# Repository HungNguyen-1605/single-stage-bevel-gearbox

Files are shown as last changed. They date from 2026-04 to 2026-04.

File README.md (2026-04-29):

# single-stage-bevel-gearbox
This is the bevel gear box designed courseworks, from random data given by professor. 
In this, i was using Maple for calculating from the top to bottom, choosing every values from catalog specifications, satisfying safety factors of materials for high durability. Visualized model on CAD Mech and 3D version for the second shaft by Inventor.

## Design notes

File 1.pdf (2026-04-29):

TRƯỜNG ĐẠI HỌC SƯ PHẠM KỸ THUẬT TP.HCM KHOA CƠ KHÍ CHẾ TẠO MÁY
BỘ MÔN CƠ SỞ THIẾT KẾ MÁY

0o0

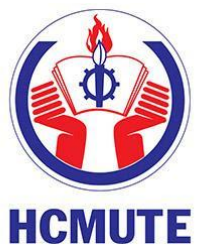
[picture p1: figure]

# THUYẾT MINH TÍNH TOÁN THIẾT KẾ

## ĐỒ ÁN THIẾT KẾ MÁY - MDPR310423

HỌ & TÊN SINH VIÊN: Nguyễn Phi Hùng
MSSV: 23146012
GIẢNG VIÊN HƯỚNG DẪN: TS.Trương Quang Tri GIẢNG VIÊN PHẢN BIỆN:

Tp. HCM, Ngày 08 tháng 01 năm 2026

Trường ĐHSPKT TP.HCM | ĐỒ ÁN THIẾT KẾ MÁY, MMH: MDPR310423
Khoa : Cơ khí Chế tạo máy | THIẾT KẾ HỆ THỐNG THÙNG TRỘN
Bộ môn: Cơ sở Thiết kế máy | Đề số: 03 – Phương án: 06
SVTH: Nguyễn Phi Hùng | MSSV: 23146012
GVHD: Trương Quang Tri | Chữ ký:
Ngày nhận đề: 25/08/2025 | Ngày bảo vệ:
I. Đề bài
Hình 1: Sơ đồ động | Hình 2: Mô hình thùng trộn

Điều kiện làm việc:

- Tải trọng không đổi, quay một chiều
- Thời gian làm việc 5 năm (300 ngày/năm, 2 ca/ngày, 6 giờ/ca)
- Sai số tỉ số truyền hệ thống |∆u/u| ≤ 5%

Số liệu cho trước:

STT | Tên gọi | Giá trị
1 | Năng suất Q (kg/giờ) | 13500
2 | Đường kính D (m) | 0,55
3 | Trọng lượng vật liệu trộn Gv (N) | 2500
4 | Góc nâng vật liệu α (độ) | 83

## Mục lục

1

### 1. Tính toán công suất, tốc độ trục công tác

1.1.Thông số đầu vào
- Năng suất: Q = 13500 (Kg/h)
- Đường kính (trong) thùng trộn: Dtℎung = 0,55 (m)
- Trọng lượng vật liệu trộn: Gvl = 2500 (N)
- Góc nâng vật liệu: α = 83 (độ)
- Các hệ số khác: φ =

1
3

; m =

1
3

; K = 200
1.2.Tốc độ trên trục công tác
Thùng trộn quay liên tục, có nghiêng của thùng so với phương ngang là β = 3

o
, vật
liệu trộn có khối lượng riêng ρ = 1300 (kg/m³
), bán kính Ro =

Dtℎung
3

= 0,1833 (m)
Tốc độ làm việc được suy ra từ công thức: [1], công thức 17-6 trang 23 Q = 60 ⋅ Ft

⋅ φ ⋅ ρ ⋅ L ⋅ m ⋅ nlv ⋅ tan(β)

trong đó: Ft

(m²

) Tiết diện ngang của thùng: Ft =

π⋅Dtℎung

2

4

=

π⋅0,55²

4

= 0,2376 (m²
)

=> L (m): Chiều dài của thùng trộn được tính theo công thức: [1], công thức 17-4 trang 22: L = m ⋅ K ⋅ Dtℎung ⋅ tan(β) =

200⋅0,55⋅tan (3)
3

= 1,9216 (m)

=> Tốc độ làm việc của thùng trộn, nlv (vg/ph):

nlv =

Q
60 ⋅ Ft

⋅ φ ⋅ ρ ⋅ L ⋅ m ⋅ tan(β)

=

13500

60 ⋅ 0,2376 ⋅

1
3

⋅ 1300 ⋅ 1,9216 ⋅

1
3

⋅ tan(β)
= 65,1 (

vg
ph)

Chuyển sang đơn vị (rad/s): ω =

nlv⋅π
30

= 6,818
1.3.Công suất quay trục công tác Ta có: Plv = P1 + P2 + P3
(kW) [1], công thức 17-7 trang 24 Trong đó:
- P1

(kW): Công suất nâng vật liệu lên độ cao thích hợp:

P1 =

Gvl ⋅ Ro ⋅ (1 − cos(α)) ⋅ ω
α ⋅

π
180

=

2500 ⋅ 0,1833 ⋅ (1 − cos(83)) ⋅ 6,818 83 ⋅

π
180
= 1,8942 (kW)

Với bán kính: Ro =

Dtℎung
3

= 0,1833 (m)
- P2

(kW): Công suất trộn vật liệu:
P2 = Gvl ⋅ Ro ⋅ ω ⋅ sin(α) ⋅ 10⁻³ = 2500 ⋅ 0,1833 ⋅ 6,818 ⋅ sin(83) ⋅ 10⁻³ = 3,1014 (kW)
- P3

(kW): Công suất mất mát do ma sát ở ổ trục thùng trộn:
P3 = 0,1 ⋅ (P1 + P2

) = 0,1 ⋅ (1,8942 + 3,1014) = 0,4996 (kW) => Công suất làm việc của thùng trộn (kW): Plv = P1 + P2 + P3 = 5,4952 (kW)

2

Bảng thống kê kết quả tính toán tốc độ và công suất làm việc:

Tốc độ quay của thùng trộn (vg/ph) | nlv = 65,1034 (vg/ph)
Công suất làm việc của trục thùng trộn (kW) | Plv = 5,4952 (kW)

### 2. Chọn động cơ, phân phối tỉ số truyền

2.1.Thông số đầu vào
- Công suất cần thiết chuyển tải liệu vít tải, Plv = 5,4952 (kW)
- Số vòng quay trục vít, nlv = 65,1 (vg/ph)
2.2.Chọn động cơ, phân phối tỉ số truyền
- Công suất cần thiết trên trục động cơ: [2], công thức 2.8, trang 19

Pctđc =

Plv
η

=

5,4952
0,84 = 6,5396 (kW)

η = ηx ⋅ ηbr ⋅ (ηol)

3
⋅ ηkn - hiệu suất truyền động toàn hệ thống ( [2], công thức 2.9, trang 19)
ηx = 0,93 - hiệu suất bộ truyền xích
ηol = 0,99 - hiệu suất truyền động 1 cặp ổ lăn
ηbr = 0,96 - hiệu suất bộ truyền bánh răng côn ηkn = 0.97 - hiệu suất truyền động khớp nối

Tra theo [2] Bảng 2.3, trang 19

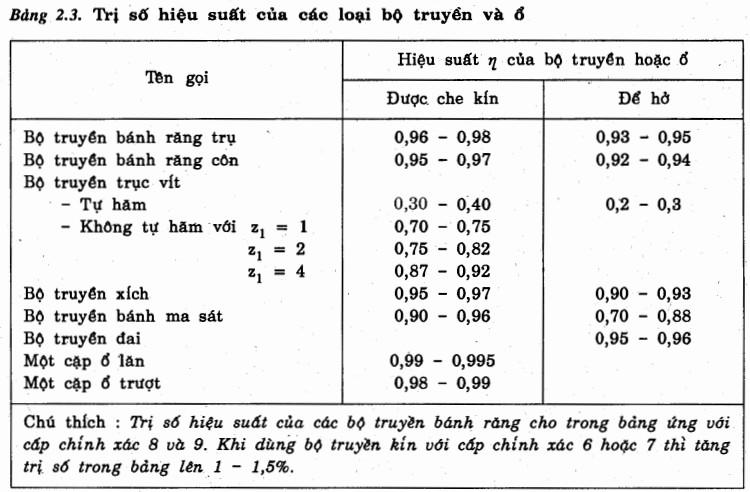
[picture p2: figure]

- Tốc độ quay sơ bộ của động cơ (vg/ph): nsb = usb ⋅ nlv = 10,65 ⋅ 65,1 = 693,35 [2], công thức 2.18, trang 21

Trong đó:

- usb(vô thứ nguyên): Tỉ số truyền sơ bộ của hệ truyền động: usb = ux ⋅ ubr = 3 ⋅ 3,55 = 10,65
ux = 3 | - Tỉ số truyền xích sơ bộ
ubr = 3,55 | - Tỉ số truyền bánh răng sơ bộ
ukn = 1 | - Tỉ số truyền của khớp nối

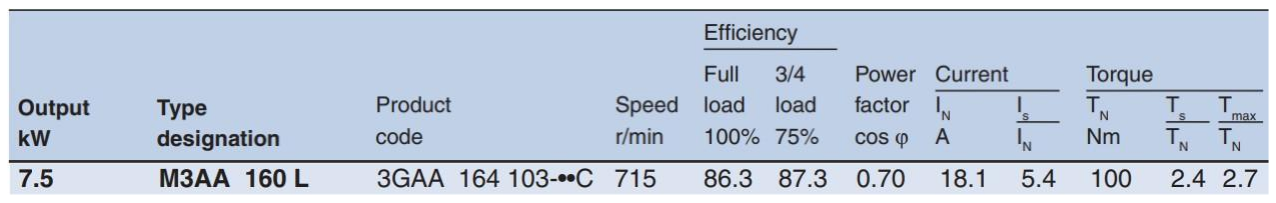
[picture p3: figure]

3

Tra theo bảng 2.4: [2], trang 21

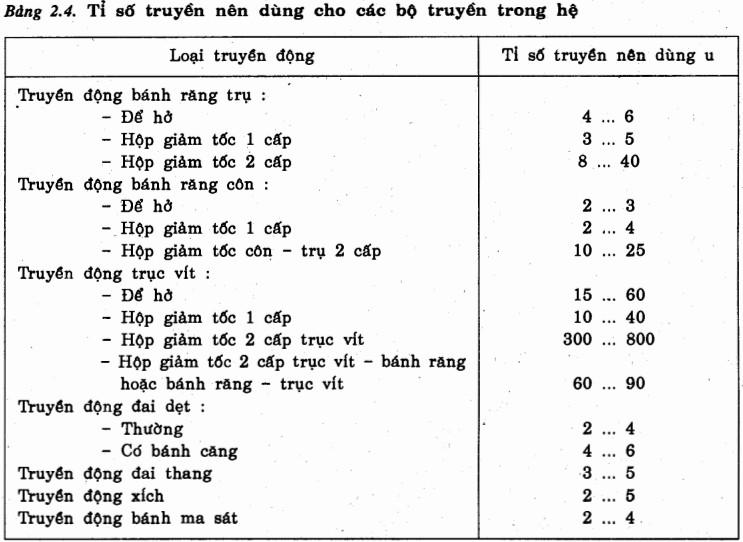
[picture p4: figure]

Điều kiện chọn động cơ: [2], công thức 2.19, trang 22

- Điện áp: 220V
- Tần số: 50Hz
- Công suất động cơ: Pdc ≥ Pctdc
- Tốc độ quay của động cơ: ndc ≈ nsb Bảng chọn kết quả: [3]
Mã động cơ (ABB) | Công suất (kW) | Tốc độ quay (vg/ph) | Ts (90%) Tn | Tmax (90%) Tn
M3AA 160 L | Pdc = 7,5 | ndc = 715 | Ts = 2,16 Tn | Tmax = 2,52 Tn
- Tính tỉ số truyền chung của hệ thống: [4], công thức 3.23, trang 48

ut =

ndc

nlv

=

715
65,1

= 10,98

- Kiểm tra sai số:z

∆u =

|ut − usb|

usb

⋅ 100% =

|10,98 − 10,65|
10,65 = 3,122% < 4%
- Tính TST bộ truyền ngoài

ux =

ut

ubr

=

10,98
3,55 = 3,09

4

2.3.Bảng thông số kỹ thuật hệ thống truyền động

Công suất trên các trục: [2], dựa vào thí dụ h.3.26, trang 49

- Công suất trục công tác (kW): PIII = Plv = 5,4952
- Công suất trục bị dẫn hộp giảm tốc (kW): PII =

PIII

ηx⋅ηol

=

5,4952
0,93⋅0,99

= 5,9685

- Công suất trên trục dẫn hộp giảm tốc (kW): PI =

PII

ηol⋅ηbr

=

5,9685
0,99⋅0,96

= 6,28

- Công suất trên trục động cơ (kW): Ptđc =

PI

ηkn

=

6,28
0,97

= 6,4742

Tốc độ quay của các trục: [2], dựa vào thí dụ h.3.26, trang 49

- Tốc độ quay trục dẫn hộp giảm tốc (vg/ph): n1 =

ndc

ukn

=

715
1

= 715

- Tốc độ quay trục bị dẫn hộp giảm tốc (vg/ph): n2 =

n1

ubr

=

715
3,55

= 201,41

- Tốc độ quay trục công tác (vg/ph): n3 =

n2
ux

=

201,41
3

= 65,10

Moment xoắn trên các trục: [2], dựa vào thí dụ h.3.26, trang 49

- Moment xoắn cần thiết trên trục động cơ (N.mm): Ttdc = 9,55 ⋅ 10⁶ ⋅

Ptdc

ndc

= 86473

- Moment xoắn trên trục dẫn hộp giảm tốc (N.mm): T1 = 9,55 ⋅ 10⁶ ⋅

PI
n1

= 83879

- Moment xoắn trên trục bị dẫn hộp giảm tốc (N.mm):T2 = 9,55 ⋅ 10⁶ ⋅

PII
n2

= 283001

- Moment xoắn trên trục công tác (N.mm): T3 = 9,55 ⋅ 10⁶ ⋅

PIII
n3

= 806085

Bảng thông số kỹ thuật hệ thống truyền động

Trục Thông số | Trục động cơ | Trục I | Trục II | Trục công tác (trục III)
Công suất, P (kW) | Ptđc =6,4742 | PI=6,28 | PII=5,9685 | PIII=5,4952
Tỉ số truyền, u | ukn = 1 | ubr = 3,55 | ux = 3,09
Số vòng quay, n (vg/ph) | ndc = 715 | nI = 715 | nII = 201,41 | nIII = 65,10
Mômen xoắn, T (N.mm) | Ttdc = 86473 | T1 = 883879 | T2 = 283001 | T3 = 806085

### 3. Tính toán, thiết kế bộ truyền xích

3.1.Thông số đầu vào
- PII = P = 5,9685(kW)
- nII = n = 201,41 (vg/ph)
- ux = u = 3,09

5

- Điều kiện làm việc: Tải trọng không đổi, quay một chiều. Thời gian làm việc 5 năm (300 ngày/năm, 2 ca/ngày, 6 giờ/ca)
3.2 Chọn loại xích

Chọn xích ống con lăn, một dãy.

Các thông số hình học xích ống con lăn xem bảng 5.2, tài liệu [2], trang 78

3.3Xác định các thông số xích, bộ truyền xích
- Tính chọn số răng đĩa xích
- Chọn sơ bộ số răng đĩa xích dẫn:
z1 = 29 − 2 ⋅ ux = 22,8 => Chọn z1 = 23 răng
- Chọn số răng đĩa xích bị dẫn:
z2 = z1

⋅ ux = 71,2 => Chọn z2 = 71 răng ≤ zmax = 120 răng
- Tỉ số truyền thực bộ truyền xích: uxtt =

z2
z1

= 3,09

- Xác định bước xích, p, theo điều kiện bền mòn

Hỏng hóc bộ truyền xích đa phần do mòn bản lề, đĩa xích do đó việc tính toán xác định bước xích thường dựa trên chỉ tiêu bền mòn bản lề

Điều kiện đảm bảo chỉ tiêu độ bền mòn, công thức 5.3 tài liệu [2] trang 81

Với xích nhiều dãy: Pt = P ⋅ k ⋅ kz
⋅ kn ≤ [P]

Trong đó:

+ Hệ số kể đến ảnh hưởng số răng đĩa xích dẫn sử dụng cho quá trình thực nghiệm xác định công suất cho phép bảng 5.5 tài liệu [2]. z01 = 25; kz =

z01
z1

=

25
23

= 1,09

+ Hệ số kể đến ảnh hưởng sự khác biệt số vòng quay đĩa xích dẫn sử dụng cho quá trình thực nghiệm xác định công suất cho phép bảng 5.5 tài liệu [2]. n01 = 200, lấy giá trị gần nhất số vòng quay đĩa xích dẫn kn =

n01
n

=

200
201,41

= 0,99

6

+ Hệ số kể đến ảnh hưởng các yếu tố khác công thức 5.4 tài liệu [2] trang 81

k = k0

⋅ ka ⋅ kđc

⋅ kbt ⋅ kđ

⋅ kc = 1 ⋅ 1 ⋅ 1,1 ⋅ 1 ⋅ 1,1 ⋅ 1,25 = 1,51

Trong đó : bảng 5.6 tài liệu [2] trang 82

kđ = 1 + 0,1 | - hệ số tải trọng động tra bảng 4.7, tài liệu [2] trang 55
k0 = 1 | - hệ số kể đến ảnh hưởng của vị trí bộ truyền
ka = 1 | - hệ số kể đến khoảng cách trục và chiều dài xích
kđc = 1,1 | - hệ số kể đến ảnh hưởng của việc điều chỉnh lực căng xích (có đĩa
căng hoặc con lăn căng xích)
kbt = 1 | - hệ số kể đến ảnh hưởng của bôi trơn (không bụi, bôi trơn mức II)
kc = 1,25 | - hệ số kể đến chế độ làm việc của bộ truyền

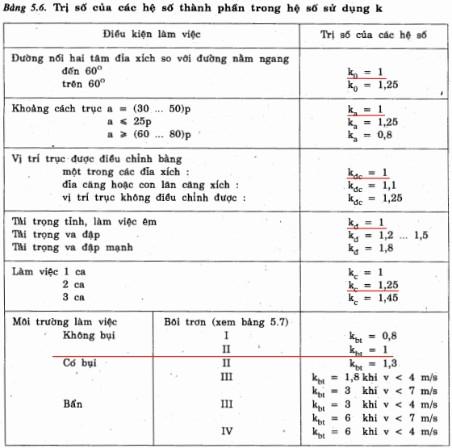
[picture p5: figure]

=>Điều kiện đảm bảo chỉ tiêu độ bền mòn: Pt = 9,7437 (kW)

tra bảng 5.5 tài liệu [2] trang 81

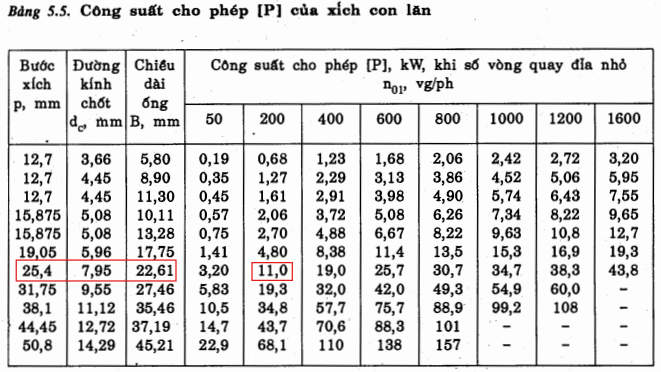
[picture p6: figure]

7

Với Pt = 9,7437 ≤ [P] = 11 (kW), ta có:

- Bước xích (mm): p = 25,4
- Đường kính chốt (mm): dc = 7,95
- Chiều dài ống (mm): B = 22,61

Kiểm tra điều kiện bước xích lớn nhất cho phép: p = 25,4 < pmax = 28,575 mm (thỏa)

- Tính khoảng cách trục và số mắt xích

Chọn sơ bộ khoảng cách trục, a = (30 ÷ 50)p = 762 ÷ 12700 => Chọn axsb =
762 (mm)

Tính số mắt xích, x, theo công thức 5.12 tài liệu [2]

x =

2 ⋅ axsb
p

+

z1 + z2
2

+

(z2 − z1

)

2
⋅ p
4 ⋅ π

2
⋅ axsb

= 2 ⋅

762
25,4

+

23 + 71
2

+

(71 − 23)

2
⋅ 25,4
4 ⋅ π

2
⋅ 762
= 108,9

=> Quy tròn về số nguyên, lấy số mắt xích chẵn xc = 110 răng

Tính khoảng cách trục, a

∗
(mm), sử dụng công thức 5.13 tài liệu [2] tr.85

a

∗ = 0,25p ⋅ {xc − 0,5(z1 + z2 ) + √ (xc + 0,5(z1 + z2
))

2
− 2 (

z2 − z1
π

)

2

}

= 0,25 ⋅ 25,4 ⋅ {110 − 0,5 ⋅ (23 + 71) + √(110 + 0,5 ⋅ (23 + 71))
2

− 2 ⋅ (

71 − 23
π

)

2

= 775,8

Tính lượng giảm khoảng cách trục:

∆a = (0,002 ÷ 0,004) ⋅ a

∗ => Chọn ∆a = 0,002 ⋅ a

∗ = 1,6 (mm)

Khoảng cách trục thiết kế, a = a

∗ − ∆a = 774,3 (mm)

- Tính kiểm nghiệm số lần va đập bản lề xích trong 1 giây, công thức 5.14 tài liệu
[2] trang 85

Trong đó: [i] tra bảng 5.9 [2] trang 85

8

i =

z1

⋅ n
15 ⋅ xc

=

23 ⋅ 201,41
15 ⋅ 110 = 2,81 < [i] = 30

3.4 Kiểm nghiệm xích về độ bền

Một số đại lượng cần thiết để xét điều kiện an toàn:

- Vận tốc xích: v =

n⋅z1⋅p
60000

=

201,41⋅23⋅25,4
60000

= 1,961 (
m
s

)

- Khối lượng một mét xích: q = 2,6 (kg) bảng 5.2
- Hệ số phụ thuộc độ võng f của xích và vị trí bộ truyền: kf = 4
- Tải trọng phá hỏng: Qpℎ = 56700 (N), [2] bảng 5.2 trang 78
- Hệ số tải trọng động: kđ = 1,1

Điều kiện bền theo hệ số an toàn: bảng 5.10 [2]

s =

Qpℎ
kđ

⋅ Ft + F0 + Fv

=

56700
1,1 ⋅ 3043,5 + 79 + 10 = 16,498 ≥ [s] = 8,2

=> Bộ truyền xích đảm bảo bền

- Lực vòng Ft = 1000 ⋅

P
v

= 3043,5 (N)
- Lực căng do lực li tâm sinh ra: Fv = q ⋅ v

2 = 10 (N)
- lực căng do trọng lượng nhánh xích bị động sinh ra, công thức 5.16 tài liệu
[2] F0 = 9,81 ⋅ kf ⋅ q ⋅ a ⋅ 10⁻³ = 79 (N)
- Hệ số an toàn cho phép tra bảng 5.10: [s]
3.5 Xác định các thông số đĩa xích và lực tác dụng lên trục

Đường kính vòng chia các đĩa xích, công thức 5.17 [2] tr.86

d1 =

p
sin(

π
z1

)

=

25,4
sin(

π
23)

= 186,5 (mm) => Chọn d1 = 187 (mm)

d2 =

p
sin(

π
z2

)

=

25,4
sin(

π
71)

= 574,2 (mm)=> Chọn d2 = 574 (mm)

Tính lực tác dụng lên trục

Giả sử:

- Bỏ qua ảnh hưởng lực căng do trọng lượng nhánh xích bị động gây ra - F0
- Bỏ qua ảnh hưởng lực căng do lực li tâm sinh ra - Fv

Công thức 5.20 tài liệu [2] trang 88, ta có:

- kx = 1,15 | - hệ số kể đến trọng lượng xích (bộ truyền nằm ngang hoặc
nghiêng dưới 40

o
- Ft = 3043,5 (N) - lực vòng

=> Fr = kx ⋅ Ft = 1,15 ⋅ 3043,5 = 3500,0 (N)

9

3.6 Bảng thông số kỹ thuật bộ truyền xích

Thông số | Ký hiệu | Giá trị | Đơn vị
Công suất trên trục dẫn | P = PII | 5,9685 | kW
Tốc độ quay trục dẫn | n = nII | 201,4 | vg/ph
Tỉ số truyền thực tế | uxtt | 3,09
Loại xích | xích ống con lăn
Số dãy xích | 1
Số răng đĩa xích dẫn | z1 | 23 | răng
Số răng đĩa xích bị dẫn | z2 | 71 | răng
Bước xích | p | 25,4 | mm
Khoảng cách trục | a | 774 | mm
Đường kính vòng chia đĩa xích dẫn | d1 | 187 | mm
Đường kính vòng chia đĩa xích bị dẫn | d2 | 574 | mm
Lực tác dụng lên trục | Fr | 3500 | N

### 4. Tính toán, thiết kế bộ truyền bánh răng

4.1.Thông số đầu vào
- Công suất trên trục bánh răng dẫn PI = 6,28 (kW)
- Tốc độ quay trục bánh răng dẫn n1 = 715 (vg/ph)
- Tốc độ quay trục bánh răng bị dẫn n2 = 201,41 (vg/ph)
- Tỉ số truyền u = ubr = 3,55
- Góc nghiêng răng β = 0 (BR côn thẳng)
- Mô men xoắn trên trục bánh răng dẫn T1 = 83879 (N.mm)
- Điều kiện làm việc:Tải trọng không đổi. Thời gian làm việc: Thời gian làm việc 5 năm (300 ngày/năm, 2 ca/ngày, 6 giờ/ca). Sai số TST hệ thống |

Δu
u

| ≤ 5%

4.2.Chọn vật liệu

Chọn vật liệu bánh răng: Tùy theo yêu cầu cụ thể như tải trọng lớn hay nhỏ, khả năng công nghệ và thiết bị chế tạo mà có thể chọn vật liệu nhóm I hoặc nhóm II. Tham khảo mục 6.1 [2]

Sau khi chọn vật liệu thống kê các thông tin như ví dụ sau:

| Vật liệu | Nhiệt luyện | Độ cứng (HB) | Giới hạn bền [σb] (Mpa) | Giới hạn chảy [σcℎ ] (Mpa)
BR dẫn | Thép C45 | Tôi cải thiện | HB1 = 230 | [σb1 ] = 750 | [σcℎ1 ] = 450
BR bị dẫn | Thép C45 | Thường hóa | HB2 = 215 | [σb2 ] = 600 | [σcℎ2 ] = 340

10

4.3. Xác định ứng suất cho phép
- Tính [σH1] và [σH2]: theo công thức 6.1a [2] trang 91

[σH1,2

] = σHlim

o
⋅

KHL
SH

(Mpa)

Trong đó:

- [σH1

]: ứng suất tiếp xúc cho phép bánh răng dẫn

- [σH2

]: ứng suất tiếp xúc cho phép bánh răng bị dẫn

- σHlim

o = 2 ⋅ HB1,2 + 70 : ứng suất tiếp xúc cho phép ứng với số chu kỳ cơ sở,

bảng 6.2 [2]

- σHlim1

o = 2HB1 + 70 = 2 ⋅ 230 + 70 = 530 (Mpa)

- σHlim2

o = 2HB2 + 70 = 2 ⋅ 215 + 70 = 500 (Mpa)
- SH = 1,1 : hệ số an toàn khi tính về tiếp xúc, [2] bảng 6.2 trang 94
- KHL = (
NHO

NHE

)

1
mH
: hệ số tuổi thọ xét đến ảnh hưởng thời gian phục vụ mH = 6 ∶

bậc đường cong mỏi khi thử về tiếp xúc (sử dụng cho trường hợp độ cứng HB ≤ 350), [2] bảng 6.7 trang 98

Với: [2] công thức 6.5 trang 93

- NHO = 30 ⋅ HB1,2

2,4
: số chu kỳ thay đổi ứng suất cơ sở khi thử tiếp xúc

=> NHO1 = 30 ⋅ HB1

2,4 = 30 ⋅ 230²,4 = 13972305,13

=> NHO2 = 30 ⋅ HB2

2,4 = 30 ⋅ 215²,4 = 11884298,69

- NHE = 60 ⋅ c ⋅ n ⋅ LH : số chu kỳ thay đổi ứng suất tương đương

c: số lần tiếp xúc/vòng quay

n: số vòng quay

LH = 6 ⋅ 2 ⋅ 300 ⋅ 5 = 18000 (giờ): tổng thời gian phục vụ

=> NHE1 = 60 ⋅ 1 ⋅ n1

⋅ LH = 60 ⋅ 715 ⋅ 18000 = 772200000

=> NHE2 = 60 ⋅ 1 ⋅ n2

⋅ LH = 60 ⋅ 201,41 ⋅ 18000 = 217521127

Chú ý: Trường hợp NHE > NHO thì lấy NHE = NHO và do đó KHL = 1 => KHL1,2 = 1

[σH1

] = σHlim1

o
⋅

KHL1
SH

= 530 ⋅

1
1,1

= 481,8182

[σH2

] = σHlim2

o
⋅

KKL2
SH

⋅

1
1,1

= 454,5455

=> ứng suất tiếp xúc cho phép: [σH] = min{[σH1 ],[σH2

]} = 454,5455 (MPa)

11

- Xác định ứng suất uốn cho phép:

Tính [σF1

] và [σF2

] theo công thức 6.2 [2]

[σF1,2

] =

σHlim

o
⋅ KFC ⋅ KFL
SF

Trong đó:

- σHlim1,2

o = 1,8HB1,2
: ứng suất uốn cho phép ứng với số chu kỳ cơ sở, bảng 6.2

[2]

- σHlim1

o = 1,8HB1 = 1,8 ⋅ 230 = 414 (MPa)

- σHlim2

o = 1,8HB2 = 1,8 ⋅ 215 = 387 (MPa)

- [σF1

]: ứng suất uốn cho phép bánh răng dẫn

- [σF2

]: ứng suất uốn cho phép bánh răng bị dẫn
- KFC = 1: hệ số xét đến ảnh hưởng đặt tải (đặt tải một phía, quay một chiều)
- SF = 1,75 : hệ số an toàn khi tính về uốn, bảng 6.2 [2] trang 94
- KFL = (
NFO

NFE

)

1
mF
: hệ số tuổi thọ xét đến ảnh hưởng chế độ tải trọng (mF = mH)

Với: NFE = 60 ⋅ c ⋅ n ⋅ LH: số chu kỳ thay đổi ứng suất tương đương

NFO = 4 ⋅ 10⁶
: số chu kỳ thay đổi ứng suất cơ sở khi thử uốn (áp dụng cho tất cả các loại thép, trang 93 [2])

NFE1 = NHE1 = 772200000 và NFE2 = NHE2 = 217521127

Chú ý: Vì NFE > NFO nên lấy NFE = NFO, và do đó KFL = 1

=> ứng suất uốn cho phép: [σF1
] = 236,5714 (Mpa) và [σF2

] = 221,1429 (Mpa)

- Ứng suất cho phép khi quá tải:

[σH]max (Mpa): (trong điều kiện nhiệt luyện thường hóa hoặc tôi cải thiện) công thức 6.13 [2] trang 95

[σH1

]max = 2,8σcℎ1 = 2,8 ⋅ 450 = 1260

[σH2

]max = 2,8σcℎ2 = 2,8 ⋅ 340 = 952

=> [σH]max = min {[σH1

]max,[σH2

]max} = 952 (Mpa)

[σF]max (Mpa): (trường hợp vật liệu có HB ≤ 350) theo công thức 6.14 [2] trang 96:

[σF1

]max = 0,8σcℎ1 = 0,8 ⋅ 450 = 360

[σF2

]max = 0,8σcℎ2 = 0,8 ⋅ 340 = 272

12

4.4. Xác định sơ bộ chiều dài côn ngoài
- Xác định sơ bộ chiều dài côn ngoài theo công thức 6.52a [2]

Re = KR ⋅ √u

2 + 1 ⋅ √
T1

⋅ KHβ
(1 − Kbe) ⋅ Kbe ⋅ u ⋅ [σH]

2

3

= 49,5 ⋅ √3,55² + 1 ⋅ √
83879 ⋅ 1,128
(1 − 0,25) ⋅ 0,25 ⋅ 3,55 ⋅ 454,5455²

3
= 161,2 (mm)

Trong đó:

- KR = 49,5 : hệ số phụ thuộc vật liệu thép - thép, răng thẳng
- Kbe = 0,25 : hệ số chiều rộng vành răng (u = 3,55 ≥ 3)
- KHβ = 1,128 : hệ số kể đến sự phân bố không đều tải trọng trên chiều rộng

vành răng bánh răng côn (tra bảng 6.21 [2] và nội suy) với

Kbe⋅u
2−Kbe

= 0,51

- [σH] = 454,5455 (Mpa) : ứng suất tiếp xúc cho phép 4.5.Xác định các thông số ăn khớp
- Đường kính chia ngoài bánh dẫn tính theo công thức 6.52b [2]

de1 =

2 ⋅ Re
√1 + u
2

=

2 ⋅ 161,2
√1 + 3,55²

= 87,4 (mm)

Xác định số răng bánh dẫn: Tính theo công thức de1 và tỉ số truyền u kết hợp phương pháp nội suy rồi tra bảng 6.22 [2]

+ Chọn được Z1p = 18
+ Số răng bánh dẫn của bánh răng côn z1 = 1,6 ⋅ Z1p = 28,8 => Chọn số nguyên z1 = 28 răng
- Tính đường kính trung bình: theo công thức 6.54 [2]: dm1 = (1 − 0,5Kbe) ⋅ de1 = (1 − 0,5 ⋅ 0,25) ⋅ 87,4 = 76,5 (mm)
- Tính mô đun trung bình theo công thức 6.56 [2]: mtm =

dm1
z1

=

76,5
28

= 2,7 (mm)

13

- Xác định mô đun vòng ngoài: mte =

mtm
1−0,5Kbe

=

2,7
1−0,5⋅0,25

= 3,1 (mm) [2] công thức

6.56

Chọn theo tiêu chuẩn bảng 6.8 [2]: mte = 4 (mm) (ưu tiên chọn dãy 1)

- Tính lại mô đun vòng trung bình theo mô đun tiêu chuẩn

mtm = mte ⋅ (1 − 0,5 ⋅ Kbe) = 4 ⋅ (1 − 0,5 ⋅ 0,25) = 3,5 (mm)

- Tính lại số răng z1
theo công thức: z1 =

dm1

mtm

=

76,5
3,5

= 21,85 => Chọn z1 = 22 răng

- Tính số răng bánh bị dẫn z2
: z2 = u ⋅ z1 = 3,55 ⋅ 22 = 78,1 => Chọn z2 = 78 răng
- Tỉ số truyền thực tế của bộ truyền bánh răng côn: ubrtt =

z2
z1

= 3,545

- Tính sai lệch tỉ số truyền hệ thống, kiểm tra điều kiện đầu bài Δuℎệ tℎống ≤ 5%

Δuℎệ tℎống =

ucℎ − ubrtt ⋅ uxtt

ucℎ

⋅ 100% = 0,345 ≤ 5%

Trong đó:

uxtt = 3,09 | - tỉ số truyền thực bộ truyền xích
ubrtt = 3,545 | - tỉ số truyền thực bộ truyền bánh răng
ucℎ = 10,98 | - tỉ số truyền chung của hệ thống
- Xác định các góc ôm chia theo công thức
| δ1 = tan⁻¹ ( z1 z2 ) = tan⁻¹ (
| 27
96) = 15,75 (độ)
| δ2 = 90 − δ1 = 90 − 15,71 = 74,25 (độ)
- Xác định đường kính trung bình, chiều dài côn ngoài theo công thức 6.65 và 6.66 [2] + Đường kính chia ngoài:
Re = 0,5 ⋅ mte ⋅ √z1 | 2 + z2 2 = 4⋅√22²+78²
| 2 = 162,1 (mm) => Chọn: Re = 162 (mm)
+ Bề rộng vành răng:

b = Kbe ⋅ Re = 0,25 ⋅ 162 = 40,525 (mm) => Chọn b = 40,5 (mm)

4.6.Xác định các kích thước hình học theo tiêu chuẩn mô đun
- Đường kính vòng chia bánh dẫn (mm): de1 = mte ⋅ z1 = 4 ⋅ 22 = 88
- Đường kính vòng chia bánh bị dẫn (mm): de2 = mte ⋅ z2 = 4 ⋅ 78 = 312

14

- Chiều cao răng ngoài (mm): ℎe = 2 ⋅ ℎte ⋅ mte + c = 8,8 (với hte = 1; c = 0,8; xn1 = 0,38; mte = 4 )
- Chiều cao đầu răng ngoài bánh dẫn (mm):

ℎae1 = ℎte + xn1

⋅ cos(β) ⋅ mte = 1 + 0,38 ⋅ cos (0) = 2,52

- Chiều cao chân răng ngoài bánh dẫn (mm):

ℎfe1 = ℎe − ℎae1 = 8,8 − 2,52 = 6,28

- Chiều cao đầu răng ngoài bánh bị dẫn (mm):

ℎae2 = 2 ⋅ ℎte ⋅ mte − ℎae1 = 2 ⋅ 1 ⋅ 4 − 2,52 = 5,48

- Chiều cao chân răng ngoài bánh bị dẫn (mm):

ℎfe2 = ℎe − ℎae2 = 8,8 − 5,48 = 3,32

- Đường kính đỉnh răng ngoài bánh dẫn (mm):

da1 = de1 + 2 ⋅ ℎae1

⋅ cos(δ1

) = 88 + 2 ⋅ 2,52 ⋅ cos(15,75) = 92,9

=> chọn da1 = 93 (mm)

- Đường kính đỉnh răng ngoài bánh bị dẫn (mm):

da2 = de2 + 2 ⋅ ℎae2

⋅ cos(δ2) = 312 + 2 ⋅ 5,48 ⋅ cos (74,25) = 314,98

=> chọn da2 = 315 (mm)

- Đường kính trung bình bánh dẫn (mm): dm1 = (1 −
0,5b
Re

) ⋅ de1 = (1 −
0,5⋅40,5

162 ) ⋅ 88 = 77 => chọn dm1 = 77 (mm)

- Đường kính trung bình bánh bị dẫn (mm): dm2 = (1 −
0,5b
Re

) ⋅ de2 = (1 −
0,5⋅40,5

162 ) ⋅ 312 = 273 => chọn dm2 = 273 (mm)

4.7.Kiểm nghiệm bền
- Kiểm nghiệm độ bền tiếp xúc

σH = ZMZHZε√
2T1KH ⋅ √u
2 + 1
0,85 ⋅ b ⋅ u ⋅ dm1

2 ≤ [σH]

Trong đó:

- ZM = 274 : hệ số kể đến cơ tính vật liệu của các bánh răng ăn khớp, bảng 6.5 [2] tr.96
- ZH = 1,76 : hệ số kể đến hình dạng bề mặt tiếp xúc, bảng 6.12 [2] tr.106
- Zε hệ số kể đến sự trùng khớp của răng Zε = √
4−εα
3
= √ | 4−1,694
| 3 = 0,87

Với: εα = [1,88 − 3,2 ⋅ (
1
z1

+

1
z2

)] ⋅ cos(β) = [1,88 − 3,2 ⋅ (
| 1
| 22 +

1

78) ⋅ cos(0)] = 1,69

15

+ KH = KHβ ⋅ KHα ⋅ KHv : hệ số tải trọng khi tính về tiếp xúc

Với:

+KHβ = 1,128 : hệ số kể đến sự phân bố không đều tải trọng trên chiều rộng vành

rang
+KHα = 1 : hệ số kể đến sự phân bố không đều tải trọng cho các đôi răng đồng thời ăn khớp (tra bảng 6.14 [2] tr.107, bánh răng côn răng thẳng = 1)
+KHv hệ số kể đến tải trọng động xuất hiện trong vùng ăn khớp:

KHv = 1 +

vH ⋅ b ⋅ dm1

2T1KHβKHα

= 1,07

Trong đó: vH = δH ⋅ go ⋅ v ⋅ √
dm1(u+1)
u

= 4,269 < vHmax = 310

Với: v =

π⋅dm1⋅n1
60000

=

π⋅77⋅715
60000

= 2,883
- δH = 0,006 (δF = 0,016): hệ số kể đến ảnh hưởng của các sai số ăn khớp, tra bảng 6.15 [2]

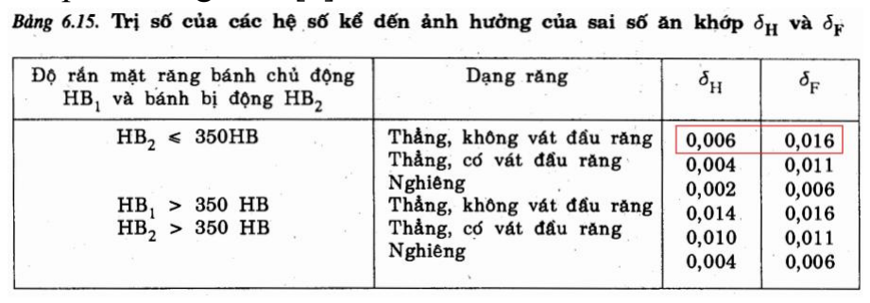
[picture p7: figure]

- go = 53 : hệ số kể đến ảnh hưởng của sai lệch các bước răng, tra bảng 6.16 [2]
- vmax = 310 (m/s): xác định từ khả năng chịu tải trọng động lớn của bánh răng, bảng 6.17 [2]

=> Hệ số tải trọng khi tính về tiếp xúc KH = KHβ ⋅ KHα ⋅ KHv = 1,21

=> Ứng suất tiếp xúc: σH = 429,3397 (Mpa) < [σH] = 454,5455 (Mpa)

16

Cần phải kiểm tra điều kiện: (trường hợp σH < [σH] )

[σH] − σH
[σH]

⋅ 100% =

454,5455 − 429,3397
454,5455 ⋅ 100% = 5,5453% ≤ 10% (thỏa)
- Kiểm nghiệm răng về độ bền uốn

Tính ứng suất uốn, và kiểm tra điều kiện bền uốn theo công thức 6.65 và 6.66 [2]

σF1 =

2T1KFYF1YεYβ
0,85 ⋅ b ⋅ mtm ⋅ dm1

= 74,137 ≤ [σF1

| ] = 236,571 (Mpa)

σF2 =

σF1YF2

YF1

= 68,434 ≤ [σF2

| ] = 221,143 (Mpa)

Trong đó:

- Yε =

1
εα

= 0,59 : hệ số kể đến sự trùng khớp của răng

- Yβ = 1 : hệ số kể đến độ nghiêng của răng
- YF1 = 4 : hệ số dạng răng của bánh dẫn, tra bảng 6.18 [2] với zv1 =
| z1
| cos³(β) = 22
- YF2 = 3,611 : hệ số dạng răng của bánh bị dẫn với zv2 =
| z2
| cos³(β) = 78

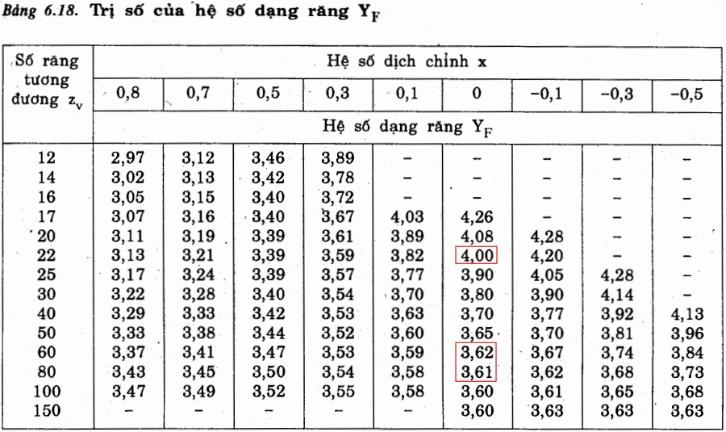
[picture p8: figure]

- KF = KFβ ⋅ KFα ⋅ KFv = 1,92 : hệ số tải trọng khi tính về uốn

Với:

+ KFβ = 1,47 : hệ số kể đến sự phân bố không đều tải trọng trên chiều rộng vành răng khi tính về uốn, tra bảng 6.21 [2]
+ KFα = 1 : hệ số kể đến sự phân bố không đều tải trọng cho các đôi răng đồng thời ăn khớp khi tính về uốn, tra bảng 6.14 [2]
+ KFv hệ số kể đến tải trọng động xuất hiện trong vùng ăn khớp khi tính về uốn tính, công thức 6.68 [2] KFv = 1 +
| vF⋅b⋅dm1 2T1KFβKFα = 1,31
| Với: vF = δF ⋅ go ⋅ v √ dm1⋅(u+1) u = 24,284

17

- Kiểm nghiệm răng về quá tải: Kqt = 1 : hệ số quá tải
=> Kiểm tra ứng suất tiếp xúc cực đại cho phép theo công thức 6.48 [2]

σHmax = σH ⋅ √Kqt = 447,713 (Mpa) ≤ [σH]max = 952 (MPa)

=> Kiểm tra ứng suất uốn cực đại cho phép theo công thức 6.49 [2]

σF1max = σF1

⋅ Kqt = 74,137 (Mpa) ≤ [σF1

]max = 360 (Mpa)

σF2max = σF2

⋅ Kqt = 68,434 (Mpa) ≤ [σF2

]max = 272 (Mpa)

4.8.Tính luật tác dụng khi ăn khớp α = 20o

: góc ăn khớp, thường lấy 20o

- Lực vòng (N): Ft1 =

2T1

dm1

= 2178,5 (N) = Ft2

- Lực hướng tâm (N): Fr1 = Ft1

⋅ tan(α) ⋅ cos(δ1

) = 763,1 = Fa2
- Lực dọc trục (N): Fa1 = Ft1

⋅ tan(α) ⋅ sin(δ1

) = 215,3 = Fr2

4.9. Bảng thông số kỹ thuật bộ truyền bánh răng
Thông số | Ký hiệu | Giá trị | Đơn vị
Công suất trục bánh răng dẫn | PI | 6,28 | kW
Tốc độ quay trục dẫn | n1 | 715 | Vg/ph
Mô men xoắn trên trục dẫn | T1 | 83879 | N.mm
Tỉ số truyền thực tế | ubrtt | 3,545
Thời gian làm việc | LH | 18000 | Giờ
Chiều dài côn ngoài | Re | 162 | mm
Mô đun vòng ngoài | mte | 4 | mm
Chiều rộng vành răng | b | 40.5 | mm
Góc côn chia bánh dẫn | δ1 | 15,75 | Độ
Góc côn chia bánh bị dẫn | δ2 | 74,25 | Độ
Số răng bánh dẫn | z1 | 22 | Răng
Số răng bánh bị dẫn | z2 | 78 | Răng
Đường kính vòng chia bánh dẫn | de1 | 88 | mm
Đường kính vòng chia bánh bị dẫn | de2 | 312 | mm
Đường kính đỉnh răng ngoài bánh dẫn | da1 | 93 | mm
Đường kính đỉnh răng ngoài bánh bị dẫn | da2 | 315 | mm
Đường kính trung bình bánh dẫn | dm1 | 77 | mm
Đường kính trung bình bánh bị dẫn | dm2 | 273 | mm
Chiều cao đầu răng ngoài bánh dẫn | ℎae1 | 2.52 | mm
Chiều cao đầu răng ngoài bánh bị dẫn | ℎae2 | 5.48 | mm

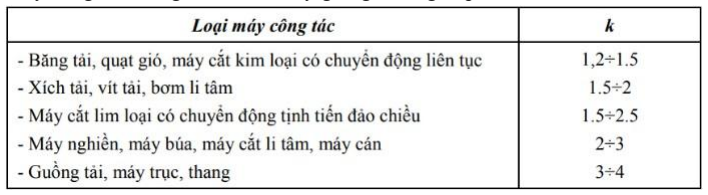
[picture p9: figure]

18

Chiều cao chân răng bánh dẫn | ℎfe1 | 6.28 | mm
Chiều cao chân răng bánh bị dẫn | ℎfe2 | 3.32 | mm

Lực tác dụng ăn khớp
Lực vòng | Ft1,2 | 2178,5 | mm
Lực hướng tâm | Fr1 = Fa2 | 763,1 | mm
Lực dọc trục | Fa1 = Fr2 | 215,2 | mm

### 5. Tính chọn nối trục

5.1.Thông số đầu vào
- Moment xoắn danh nghĩa cần truyền (trục vào): T = Ttdc = 86473 (N.mm)
- Đặc trưng tải trọng: Thùng trộn
5.2. Chọn nối trục
- Xác định moment xoắn tính toán T = Ttdc = 86473 (N.mm)
+ Mômen xoắn danh nghĩa trên trục
+ Hệ số an toàn làm việc, phụ thuộc vào loại máy công tác, tra bảng 9.1 [4] tr.229, máy công tác thùng trộn có thể lấy giống trường hợp vít tải k = 1,5

=> Moment xoắn tính toán trục vào: Tt = k ⋅ T ⋅ 10⁻³ = 130 (N. m)

- Tính sơ bộ đường kính trục tại vị trí lắp nối trục
+ Moment xoắn cần truyền trên trục lắp nối trục T = 86473,3147 (N.mm)
+ Ứng suất trượt cho phép. Giả sử chọn vật liệu làm trục là thép 45
[τ] = 15 ÷ 30 (Mpa). Với hộp giảm tốc, trị số nhỏ sử dụng cho trục dẫn – trục vào τv = 15 (Mpa); trị số lớn sử dụng cho trục bị dẫn – trục ra τr = 30 (Mpa)

=> Tính đường kính trục sơ bộ tại vị trí lắp nối trục

d ≥ √
Tt
0,2⋅τv

⋅ 10³

3

= √
130
0,2⋅15

3
= 35,1 (mm) => Chọn theo tiêu chuẩn d = 36 (mm)

Dựa trên giá trị moment xoắn tính toán, đường kính trục sơ bộ ở bước trên, chọn nối trục phù hợp theo bảng 9.10a, kích thước vòng đàn hồi, chốt bảng 9.10b [4] tr.239

19

Bảng 9.10a Kích thước cơ bản của nối trục vòng đàn hồi [4]

Bảng 9.10b Kích thước cơ bản của vòng đàn hồi [4] với Tt = 130 (N.mm)

Thông số tính toán cơ bản của nối trục:

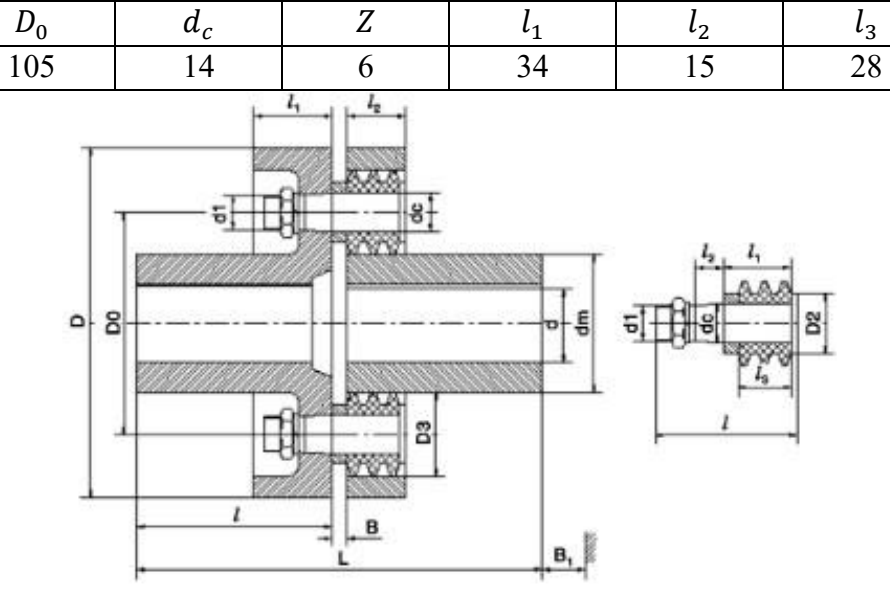
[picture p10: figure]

Hình nối trục vòng đàn hồi

5.3. Tính kiểm nghiệm bền
- Điều kiện sức bền dập của vòng đàn hồi theo công thức (9.11) [5]

σd =

2 ⋅ k ⋅ T
Z ⋅ D0

⋅ dc

⋅ l3

=

2 ⋅ 1,5 ⋅ 86473
6 ⋅ 105 ⋅ 14 ⋅ 28 = 1,05 ≤ [σd

] = 2 (Mpa)

- Điều kiện sức bền uốn của chốt theo công thức (9.12) [5]

σu =

k ⋅ T ⋅ l0
0,1 ⋅ D0

⋅ dc

3
⋅ Z

=

k ⋅ T ⋅ (l1 +

l2
2

)

0,1 ⋅ D0

⋅ dc

3
⋅ Z

=

1,5 ⋅ 86473 ⋅ 41,5
0,1 ⋅ 105 ⋅ 14³
⋅ 6

= 31,14 ≤ [σu

] = 60 (Mpa)

20

5.4. Tính lực tác dụng lên trục
- Tính lực hướng tâm nối trục Frnt, sinh ra do sự không đồng tâm khi lắp hai nửa khớp nối lên các trục, giá trị Frnt có thể lấy gần đúng như sau:

Frnt =

0,2 ⋅ 2 ⋅ T
D0

=

0,2 ⋅ 2 ⋅ 86473
14 = 329,4 (N)
- Moment xoắn: T = Ttdc = 86473

### 6. Tính toán thiết kế trục và chọn then

6.1. Thông số đầu vào

Trục 1
lực tác dụng lên trục từ bộ truyền xích (N) | Frx = 3500
moment xoắn trên trục I (N.mm) | T1 = 83879
góc nghiêng bộ truyền xích (độ) | α = 30
lực nối trục (lực hướng tâm) (N) | Frnt = 329,4
lực tiếp tuyến (lực vòng) bộ truyền bánh răng (N) | Ft1 = 2178,5
lực hướng tâm bộ truyền bánh răng (N) | Fr1 = 763,1
lực dọc trục bộ truyền bánh răng (N) | Fa1 = 215,2
đường kính trung bình bánh dẫn (mm) | dm1 = 77

Trục 2
lực dọc trục bộ truyền bánh răng (N) | Fa2 = 763,1
lực hướng tâm bộ truyền bánh răng (N) | Fr2 = 215,2
lực tiếp tuyến (lực vòng) bộ truyền bánh răng (N) | Ft2 = 2178,5
moment xoắn cần truyền trên trục (N.mm) | T2 = 283001
lực tác dụng lên trục từ bộ truyền xích (N) | Frx = 3500
góc nghiêng bộ truyền xích (độ) | α = 30
đường kính trung bình bánh bị dẫn (mm) | dm2 = 273

6.2.Chọn vật liệu

Vật liệu | Nhiệt luyện | Độ cứng (HB) | Giới hạn bền σb (Mpa) | Giới hạn chảy σcℎ (Mpa)
Thép C45 | Tôi cải thiện | HB = 250 | σb = 850 | σcℎ = 580

21

6.3. TÍnh toán thiết kế trục theo điều kiện bền, chọn then
- Sơ đồ động:

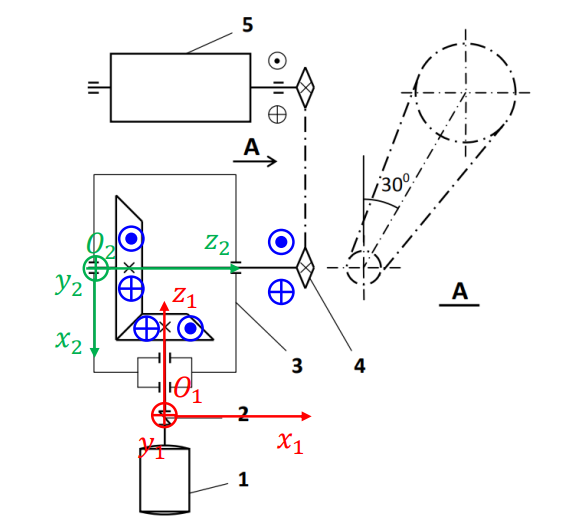
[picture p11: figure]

Xác định sơ bộ đường kích trục theo điều kiện bền cắt

- Đường kính trục 1 sơ bộ với τv = 15 (MPa)

d ≥ √
T1
0,2⋅τv

3

= √
83879
0,2⋅15

3
= 30,4 => Chọn d1 = 35 (mm)
- Đường kính trục 2 sơ bộ với τr = 30 (MPa)

d ≥ √
T2
0,2⋅τv

3

= √
283001
0,2⋅30

3
= 36,1 => Chọn d2 = 40 (mm)
- Xác định chiều dài các đoạn trục, khoảng cách giữa các gối đỡ và điểm đặt lực theo hình 10.10 [2]
+ Bề rộng ổ theo bảng 10.2 [2] tr.189
- Trên trục 1: b01 = 21 (mm)
- Trên trục 2: b02 = 23 (mm)
+ Chiều dài mayơ nửa khớp nối i = 2 trên trục thứ nhất k = 1
lm12 = (1,4 ÷ 2,5) ⋅ d1 = 1,4 ⋅ d1 = 1,4 ⋅ 35 = 49 (mm) + Chiều dài mayơ bánh bánh răng côn i = 3 trên trục thứ nhất k = 1 lm13 = (1,2 ÷ 1,4) ⋅ d1 = 1,2 ⋅ d1 = 1,2 ⋅ 35 = 42 (mm) + Chiều dài mayơ đĩa xích i = 2 trên trục thứ hai k = 2
lm22 = (1,2 ÷ 1,5) ⋅ d2 = 1,2 ⋅ d2 = 1,2 ⋅ 40 = 48 (mm) + Chiều dài mayơ bánh răng côn i = 3 trên trục thứ hai k = 2 lm23 = (1,2 ÷ 1,4) ⋅ d2 = 1,2 ⋅ d2 = 1,2 ⋅ 40 = 48 (mm) + Trị số của các khoảng cách, xác định theo bảng 10.3 [2] tr.189 k1 = 10; k2 = 10; k3 = 10; ℎn = 25,6

22

+ | Khoảng trục công xôn chìa ra ngoài gắn với bánh đai, nối trục,lc12, lc22 tính
| theo công thức 10.14 [4]

lc12 =

(lm12 + b01)
2

+ k3 + ℎn =

49 + 21
2

+ 10 + 25,6 = 70,6 (mm)

lc22 =

(lm22 + b02)
2

+ k3 + ℎn =

48 + 23
2

10 + 25,6 = 71,1 (mm)

+ | Khoảng cách từ gối đỡ 0 đến 1 theo bảng 10.4
| l11 = (2,5 ÷ 3) ⋅ d1 = 2,5 ⋅ d1 = 2,5 ⋅ 35 = 87,5 (mm)
+ | Khoảng cách từ gối đỡ 0 đến 1 theo bảng 10.4
| l12 = −lc12 = −65 (mm) (nằm bên trái ổ lăn gốc B)
+ | Khoảng cách từ gối đỡ 0 đến bánh răng theo bảng 10.4:
| l13 = l11 + k1 + k2 + lm13 + 0,5 ⋅ (b01 − b13 ⋅ cos(δ1 ))
| = 87,5 + 10 + 10 + 42 + 0,5 ⋅ (21 − 40,5 ⋅ cos(15,75)) = 140,5 (mm)
+ Khoảng cách từ gối đỡ 0 đến trục đối xứng nằm giữa ổ lăn 0 và ổ lăn 1:
| X = dm1
| 2 + lm23 + k1 + k2 + b0
| 2 − 7
| =
| 77
| 2 + 48 + 10 + 10 +
| 23
| 2 − 7 = 111 (mm)
+ Khoảng cách từ gối đỡ 0 đến gối đỡ 1: l21 = 2 ⋅ X = 2 ⋅ 111 = 222 (mm) + Khoảng cách từ gối đỡ 0 đến đĩa xích: lc22 = 71,1 (mm)
+ Khoảng cách từ gối đỡ 0 đến bánh răng theo bảng:
| l23 = X + dm1
| 2 = 111 +
| 77
| 2 = 149,5 (mm)

Lưu ý: l21, l23 được tính theo ngữ cảnh hộp giảm tốc 1 cấp

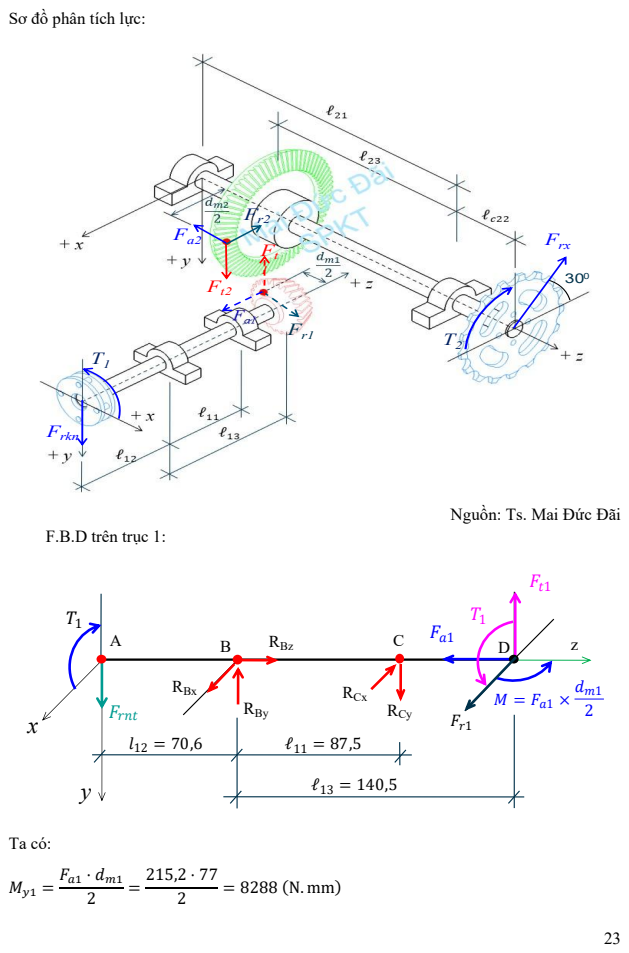
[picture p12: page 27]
F.B.D trên trục 1:; RBy; RCx; RCy; RBx

Sơ đồ phân tích lực:

Nguồn: Ts. Mai Đức Đãi

24

- Xét mặt phẳng YOZ:
ΣMB = −Frnt ⋅ l12 + RCy ⋅ l11 − Ft1

⋅ l13 = 0
=> RCy =

Frnt⋅l12+Ft1⋅l13
l11

=

329,4⋅70,6+2178,5⋅140,5
87,5

= 3764,1(N)

ΣFy = Frnt − RBy + RCy − Ft1 = 0

=> RBy = Frnt + RCy − Ft1 = 329,4 + 3764,1 − 2178,5 = 1915 (N)

- Xét mặt phẳng XOZ

ΣMB = −RCx ⋅ l11 + Fr1

⋅ l13 − My1 = 0

=> RCx =

Fr1⋅l13−My1
l11

=

763,1⋅140,5−8287,5
87,5

= 1130,7 (N)

ΣFx = RBx − RCx + Fr1 = 0

=> RBx = RCx − Fr1 = 1130,7 − 763,1 = 367,6 (N)

Thông số đầu vào trục 1:

Frnt = 329,4 | N
T = 83879 | N.mm
RBx = 367,6 | N
RBy = 1915 | N
RCx = 1130,7 | N
RCy = 3764,1 | N
Fa1 = 215,2 | N
Fr1 = 763,1 | N
Ft1 = 2178,5 | N
My1 = 8288 | N.mm
l11 = 87,5 | mm
l12 = 70,6 | mm
l13 = 140,5 | mm

Mx: Mxmax = max{MxA, MxB, MxC, MxD} = 115482 (N. mm)

MxA = 0 (N. mm)

MxB = Frnt ⋅ l12 = 329,4 ⋅ 70,6 = 23257 (N. mm)

MxC = Ft1

⋅ (l13 − l11) = 2178,5 ⋅ (140,5 − 87,5) = 115482 (N. mm)

MxD = 0 (N. mm)

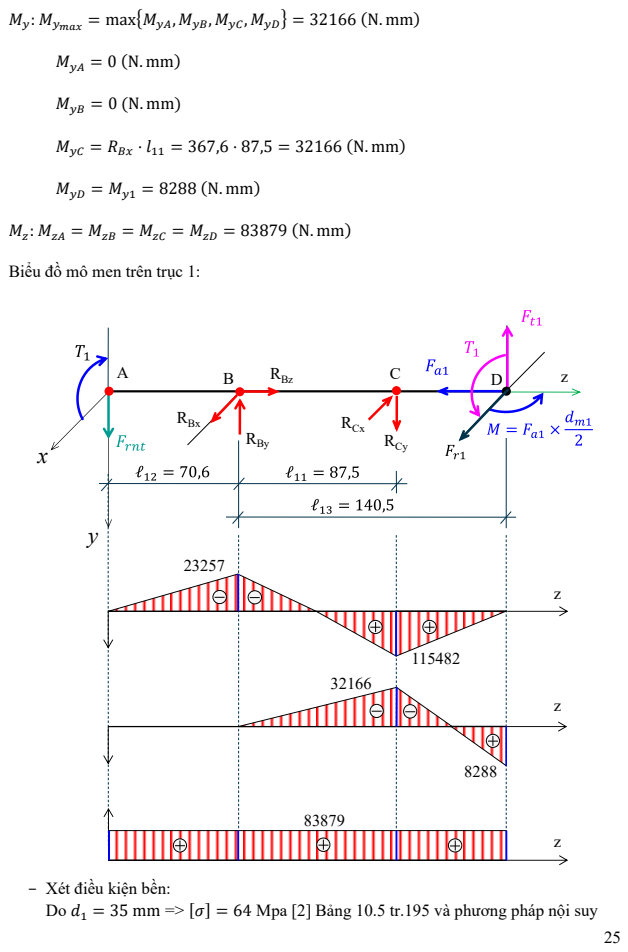
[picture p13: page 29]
MyA = 0 (N. mm); MyB = 0 (N. mm); MyD = My1 = 8288 (N. mm); RBy; RCx; RCy; RBx; RBz

My: Mymax = max{MyA, MyB, MyC, MyD} = 32166 (N. mm)

MyC = RBx ⋅ l11 = 367,6 ⋅ 87,5 = 32166 (N. mm)

: MzA = MzB = MzC = MzD = 83879 (N. mm)

Biểu đồ mô men trên trục 1:

- Xét điều kiện bền:
Do d1 = 35 mm => [σ] = 64 Mpa [2] Bảng 10.5 tr.195 và phương pháp nội suy

26

σeq1

max =

√Mx_max
2 | + My_max
2 | + 0,75 ⋅ Mz_max

2
0,1 ⋅ d1

3

=

√115482,4
2 + 32166,3

2 + 0,75 ⋅ 83879²
0,1 ⋅ 35³ | = 32,693 (MPa) ≤ [σ] = 64 (MPa)
- Trên từng đoạn trục (đoạn chịu lực), tính chọn đường kính trục + Đường kính trục lắp nối trục tại A:

d1 ≥ (
√0,75 ⋅ Mz
2
0,1 ⋅ [σ]

)

1
3

= (
√0,75 ⋅ 83879²

0,1 ⋅ 64 )

1
3
= 22,5 (mm)

+ Đường kính trục lắp ổ lăn tại B:

d2 ≥ (

√Mx
2 + My

2 + 0,75 ⋅ Mz

2
0,1 ⋅ [σ]

)

1/3= (
√23257,2
2 + 0.75 ⋅ 83879,1

2

0,1 ⋅ 64 | )

1
3

= 22,8(mm)
+ Đường kính trục lắp ổ lăn tại C:

d3 ≥ (

√Mx
2 + My

2 + 0,75 ⋅ Mz

2
0,1 ⋅ [σ]

)

1
3

= (
√115482,4
2 + 32166,3

2 + 0,75 ⋅ 83879,1

2

0,1 ⋅ 64 | )

1
3
= 28 (mm)

+ Đường kính trục lắp bánh răng côn dẫn tại D:

d4 ≥ (

√Mx
2 + My

2 + 0,75 ⋅ Mz

2
0,1 ⋅ [σ]

)

1/3= (
√8287,5 | 2 + 0,75 ⋅ 83879,1
2
0,1 ⋅ 64 | )

1
3

= 22,5 (mm)

Xuất phát từ yêu cầu về độ bền, lắp ghép và công nghệ ta chọn đường kính các đoạn trục như sau :
d1 = 24 (mm) | Vị trí lắp nối trục tại A:
d2 = 30 (mm) | Vị trí lắp ổ lăn tại B
d3 = 30 (mm) | Vị trí lắp ổ lăn tại C
d4 = 24 (mm) | Vị trí lắp bánh răng côn dẫn tại D

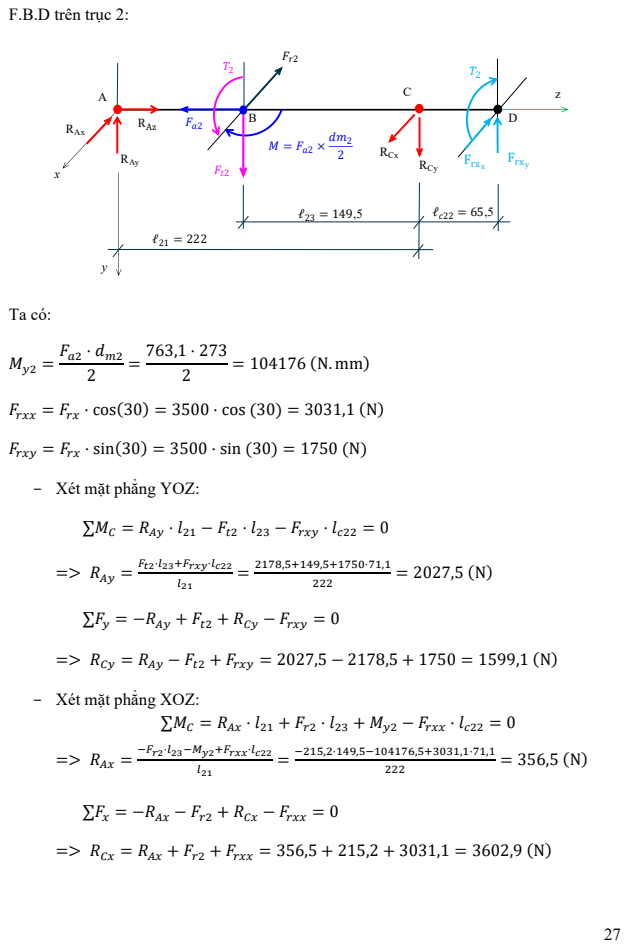
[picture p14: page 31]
F.B.D trên trục 2:; ∑MC = RAy ⋅ l21 − Ft2; ⋅ l23 − Frxy ⋅ lc22 = 0; => RAy =; Ft2⋅l23+Frxy⋅lc22; ∑MC = RAx ⋅ l21 + Fr2; ⋅ l23 + My2 − Frxx ⋅ lc22 = 0; => RAx =; −Fr2⋅l23−My2+Frxx⋅lc22; RCx; RCy

Frxx = Frx ⋅ cos(30) = 3500 ⋅ cos (30) = 3031,1 (N)

Frxy = Frx ⋅ sin(30) = 3500 ⋅ sin (30) = 1750 (N)

- Xét mặt phẳng YOZ:

∑Fy = −RAy + Ft2 + RCy − Frxy = 0

=> RCy = RAy − Ft2 + Frxy = 2027,5 − 2178,5 + 1750 = 1599,1 (N)

- Xét mặt phẳng XOZ:

∑Fx = −RAx − Fr2 + RCx − Frxx = 0

=> RCx = RAx + Fr2 + Frxx = 356,5 + 215,2 + 3031,1 = 3602,9 (N)

28

- Thông số đầu vào trục 2

Mx (N, mm) ∶ Mxmax = max{MxA, MxB, MxC, MxD} = 146996

MxA = 0

MxB = RAy ⋅ (l21 + l23) = 1983,4 ⋅ (222 − 149,5) = 146996

MxC = Frxy ⋅ lc22 = 1750 ⋅ 71,1 = 124426

MxD = 0

My (N. mm) ∶ Mymax = max{MyA, MyB, MyC, MyD} = 215513

MyA = 0

MyB1 = RAx ⋅ (l21 − l23) = 356,5 ⋅ (222 − 149,5) = 25850

MyB2 = RAx ⋅ (l21 − l23) + My2 = 356,5 ⋅ (222 − 149,5) + 104176 = 130026

MyC = Frxx ⋅ lc22 = 3031,1 ⋅ 71,1 = 215513

MyD = 0

Mz (N. mm) ∶ MzB = MzC = MzD = 283001; MzA = 0

Frxx = 3031,1 | N
Frxy = 1750 | N
RAx = 356,5 | N
RAy = 2027,5 | N
RCx = 3602,9 | N
RCy = 1599,1 | N
l21 = 222 | mm
lc22 = 71,1 | mm
l23 = 149,5 | mm
T2 = 283001 | N.mm

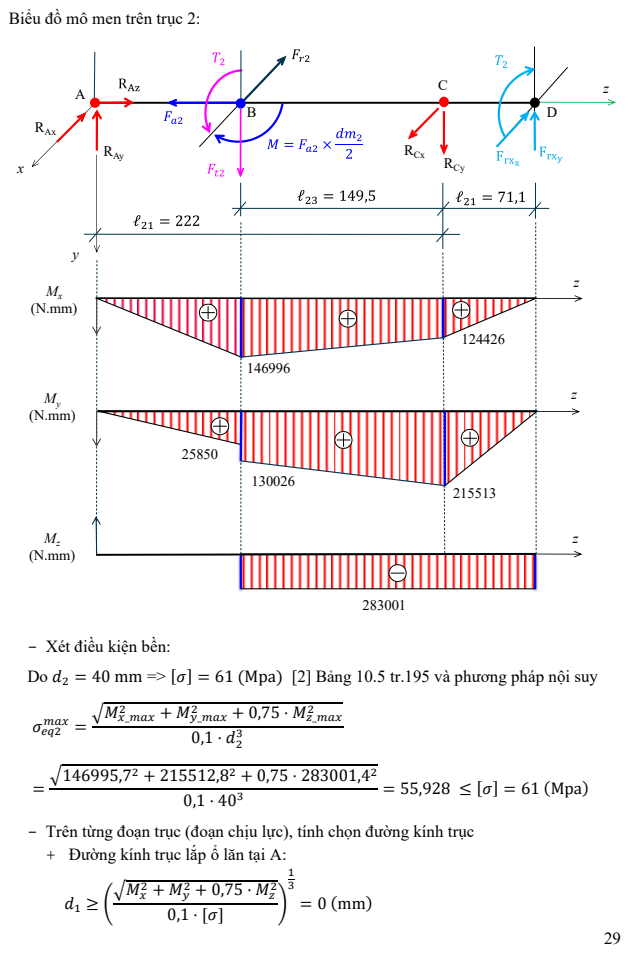
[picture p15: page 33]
σeq2; max =; √Mx_max; + My_max; + 0,75 ⋅ Mz_max; = 55,928 ≤ [σ] = 61 (Mpa); RAy; RCx; RCy; RAx

Biểu đồ mô men trên trục 2:

- Xét điều kiện bền:

Do d2 = 40 mm => [σ] = 61 (Mpa) [2] Bảng 10.5 tr.195 và phương pháp nội suy

- Trên từng đoạn trục (đoạn chịu lực), tính chọn đường kính trục
+ Đường kính trục lắp ổ lăn tại A:

30

+ Đường kính trục lắp bánh răng côn bị dẫn tại B:

d2 ≥ (

√Mx
2 + My

2 + 0,75 ⋅ Mz

2
0,1 ⋅ [σ]

)

1
3

= (
√146995,7
2 + 130026,2

2 + 0,75 ⋅ 283001,4

2

0,1 ⋅ 61 | ) = 37,2 (mm)

+ Đường kính trục lắp ổ lăn tại C:

d3 ≥ (

√Mx
2 + My

2 + 0,75 ⋅ Mz

2
0,1 ⋅ [σ]

)

1
3

= (
√124426,4
2 + 215512,8

2 + 0,75 ⋅ 283001,4

2

0,1 ⋅ 61 | )

1
3
= 38,5 (mm)

+ Đường kính trục lắp đĩa xích tại D:

d4 ≥ (
√0,75 ⋅ Mz
2
0,1 ⋅ [σ]

)

1
3

= (
√0,75 ⋅ 283001,4
2

0,1 ⋅ 61 )

1
3
= 34,3 (mm)

Chọn đường kính các đoạn trục như sau :
d1 = 40 (mm) | (Vị trí lắp ổ lăn)
d2 = 42 (mm) | (Vị trí lắp bánh răng côn bị dẫn)
d3 = 40 (mm) | (Vị trí lắp ổ lăn)
d4 = 36 (mm) | (Vị trí lắp đĩa xích)
- Tính và chọn then cho các đoạn trục

Theo bảng 9.1a theo TCVN 2261-77 (then bằng) [2]

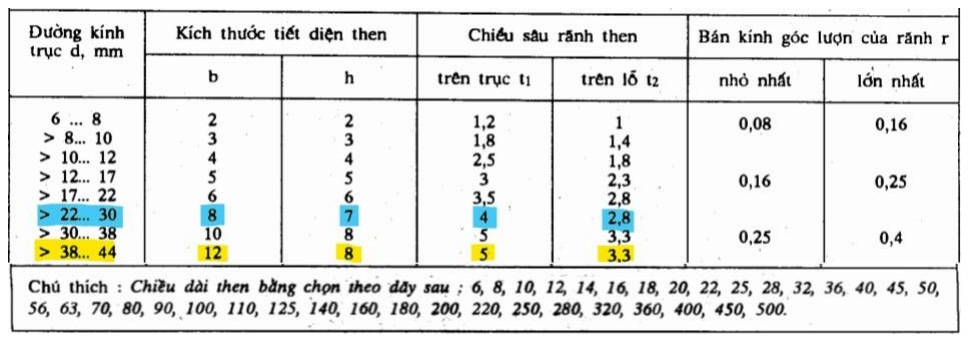
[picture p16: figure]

Trong đó, chiều dài then được tính theo công thức trang 172 [2]:

Chiều dài then ở vị trí lắp nối trục: lt12 = 0,8 ⋅ lm12 = 39,2 => lt12 = 40 (mm)

Chiều dài then ở vị trí lắp bánh răng dẫn: lt13 = 0,8 ⋅ lm13 = 33,6 => lt13 = 40(mm)

Chiều dài then ở vị trí đĩa xích: lt22 = 0,8 ⋅ lm22 = 38,4 => lt22 = 40 (mm)

Chiều dài then ở vị trí bánh răng bị dẫn: lt23 = 0,8 ⋅ lm23 = 38,4 => l
t23 = 40 (mm)

31

Bảng thông số tính toán của then:

Vị trí lắp | Kích thước tiết diện ren (mm) | Chiều sâu rãnh trên trục (mm) | Chiều sâu rãnh trên lỗ (mm) | Chiều dài then (mm)
Trục 1 | Nối trục dA = 24 mm | b12 = 8, ℎ12 = 7 | t112 = 4 | t212 = 2,8 | lt12 = 40
| Bánh răng dẫn dD = 24 mm | b13 = 8, ℎ13 = 7 | t113 = 4 | t213 = 2,8 | lt13 = 40
Trục 2 | Đĩa xích dD = 36 mm | b22 = 12, ℎ22 = 8 | t122 = 5 | t222 = 3,3 | lt22 = 40
| Bánh răng bị dẫn dB = 42 mm | b23 = 12, ℎ23 = 8 | t123 = 5 | t223 = 3,3 | lt23 = 40
- Kiểm nghiệm bền dập và bền cắt theo công thức 9.1, 9.2 [3]:

Tra bảng 9.5 được:

+ [σd

] = 150 MPa: Dạng lắp cố định và đặc tính tải trọng tĩnh + [τc

] = 60 ÷ 90 MPa: Then bằng thép C45 chịu tải trọng tĩnh Trục 1:
Vị trí lắp nối trục:

σd12 =

2 ⋅ T1

dA ⋅ lt12 ⋅ (ℎ12 − t112)

=

2 ⋅ 83879,1
24 ⋅ 40 ⋅ (7 − 4)

= 58,249 ≤ [σd

] = 150 (MPa)

τc12 =

2 ⋅ T1
dA ⋅ lt12 ⋅ b12

=

2 ⋅ 83879,1
24 ⋅ 40 ⋅ 8

= 21,844 ≤ [τc

] = 60 ÷ 90 (MPa)

Vị trí lắp bánh răng:

σd13 =

2 ⋅ T1

dD ⋅ lt13 ⋅ (ℎ13 − t113)

=

2 ⋅ 83879,1
24 ⋅ 40 ⋅ (7 − 4)

= 58,249 ≤ [σd

] = 150 (MPa)

τc13 =

2 ⋅ T1
dD ⋅ lt13 ⋅ b13

=

2 ⋅ 83879,1
24 ⋅ 40 ⋅ 8

= 21,844 ≤ [τc

] = 60 ÷ 90 (MPa)

Trục 2:
Vị trí lắp đĩa xích:

σd22 =

2 ⋅ T2

dD ⋅ lt22 ⋅ (ℎ22 − t122)

=

2 ⋅ 281001,4
36 ⋅ 40 ⋅ (8 − 5)

= 131,019 ≤ [σd

] = 150 (MPa)

τc22 =

2 ⋅ T2
dD ⋅ lt22 ⋅ b22

=

2 ⋅ 281001,4
36 ⋅ 40 ⋅ 12 = 32,755 ≤ [τc

] = 60 ÷ 90 (MPa)

32

Vị trí lắp bánh răng:

σd23 =

2 ⋅ T2

dB ⋅ lt23 ⋅ (ℎ23 − t123)

=

2 ⋅ 281001,4
42 ⋅ 40 ⋅ (8 − 5)

= 112,302 ≤ [σd

] = 150 (MPa)

τc23 =

2 ⋅ T2
dB ⋅ lt23 ⋅ b23

=

2 ⋅ 281001,4
42 ⋅ 40 ⋅ 12 = 28,076 ≤ [τc

] = 60 ÷ 90 (MPa)

6.4.Tính kiểm nghiệm bền

Kiểm nghiệm trục về độ bền mỏi tại các tiết diện nguy hiểm theo công thức (10.19) [2]

sj =

sσj ⋅ sτj

√sσj
2 + sτj

2

≥ [s]

Trong đó:

- [s]: hệ số an toàn cho phép. Thông thường [s]=1,5...2,5, khi cần tăng độ cứng lấy [s] = 2,5 ÷ 3,0 khi đó có thể bỏ qua khâu kiểm nghiệm về độ cứng của trục.
- sσj, sτj : hệ số an toàn chỉ xét riêng ứng suất pháp, ứng suất tiếp tại tiết diện j

sσj =

σ−1

Kσdj ⋅ σaj + ψσ ⋅ σmj

; sτj =

τ−1

Kτdj ⋅ τaj + ψτ

⋅ τmj

- σ−1

, τ−1

: giới hạn mỏi uốn, xoắn ứng với chu kỳ đối xứng, đối với thép carbon có thể lấy σ−1 = 0,436 ⋅ σb = 370,6 (MPa); τ−1 = 0,58 ⋅ σ−1 = 214,948 (MPa)
- σaj, τaj, σmj, τmj : biên độ và trị số trung bình của ứng suất pháp và ứng suất tiếp tại tiết diện j. Đối với trục quay, ứng suất uốn thay đổi theo chu kì đối xứng do đó:

σmj = 0

σaj = σmaxj =

Mj
Wj

; Mj = √Mx
2 + My

2
; Wj =

π ⋅ dj

3
32

Khi trục quay 1 chiều, ứng suất tiếp thay đổi theo chu kì mạch động, do đó:

τmj = τaj =

τmaxj
2

=

Tj
2 ⋅ Wρj

; Wρj =

π ⋅ dj

3
16

Đối với trục có 1 rãnh then: (b,t1
- tra bảng 9.1a [2])

Wj =

π ⋅ dj

3
32 −

b ⋅ t1

⋅ (dj − t1)

2

2 ⋅ dj

; Wρj =

π ⋅ dj

3
16 −

b ⋅ t1

⋅ (dj − t1)

2

2 ⋅ dj

- ψσ, ψτ

: hệ số kể đến ảnh hưởng của trị số ứng suất trung bình đến độ bền mỏi, bảng 10.7 [4] => ψσ = 0,1; ψτ = 0,05
- Kσdj,Kτdj: hệ số xác định theo các công thức 10.25, 10.26 [2]

33

Kσdj =

Kσ
εσ

+ Kx − 1

Ky

; Kτdj =

Kτ
ετ

+ Kx − 1

Ky
- Kx = 1,11875 : hệ số tập trung ứng suất do trạng thái bề mặt, phụ thuộc vào phương pháp gia công và độ nhám bề mặt, bảng 10.8 [2]
Ky = 1,35 : hệ số tăng bền bề mặt trục, bảng 10.9
- εσ, ετ

: hệ số kích thước kể đến ảnh hưởng của kích thước tiết diện trục đến giới hạn mỏi, bảng 10.10 [2]
- Kσ,Kτ

: hệ số tập trung ứng suất thực tế khi uốn và xoắn, trị số của chúng phụ thuộc vào loại yếu tố gây tập trung ứng suất. Tại các bề mặt trục lắp có độ dôi, có thể tra trực tiếp tỉ số

Kσ
εσ

;

Kτ
ετ

bảng 10.11 [2]. Đối với rãnh then tra bảng 10.12 [2]

Trục 1:
- Tại vị trí lắp nối trục A: TA = 83879 (N. mm)
dA = 24 mm

Do MA = √MxA
2 + MyA

2 = 0 (N. mm) nên chỉ kiểm tra hệ số an toàn chỉ tính riêng

ứng suất tiếp
Vị trí có lắp then, nên ta tra bảng 10.12 [2] tr.199 và nội suy nếu cần, ta được:

ετA = 0,858 và KτA = 1,965 =>

KτA

ετA

= 2,29

Tra bảng 10.11 chọn kiểu lắp k6 ta được: Kτ
ετ

= 1,92 <

KτA

ετA

= 2,29 => chọn

KτA

ετA

= 2,29

KτdA =

KτA
ετA

+ Kx − 1

Ky

= 1,784

WρA =

π ⋅ dA

3
16 −

b12 ⋅ t112 ⋅ (dA − t112)

2

2 ⋅ dA

= 2447,7 (mm³
)

=> τmA = τaA =

τmaxA
2

=

TA
2 ⋅ WρA

= 17,134 (MPa)

=> sτA =

τ−1

KτdA

⋅ τaA + ψτ

⋅ τmA

= 6,839 = sA ≥ [s] = 1,5. . .2,5

- Tại vị trí lắp ổ lăn B:
TB = 83879 (N. mm)

MB = √MxB
2 + MyB

2 = √23257,2
2 + 0

2 = 23257,2 (N. mm)

dB = 30 mm

34

WB =

π ⋅ dD

3
32 = 2650,7 (mm³
) => σaB =

MB
WB

= 8,774 (MPa); σmD = 0 (MPa)

Chi tiết lắp không có then nên ta lắp chặt, tra bảng 10.11 chọn kiểu lắp k6 ta được:

KσB

εσB

= 2,535

KσdB =

KσB
εσB

+ Kx − 1

Ky

= 1,966 => sσB =

σ−1

KσdB

⋅ σaB + ψσ ⋅ σmB

= 21,487

Chi tiết lắp không có then nên ta lắp chặt, tra bảng 10.11 chọn kiểu lắp k6 ta được:

KτB

ετB

= 1,92

WρB =

π ⋅ dB

3
16 = 5301,4 (mm³
)

KτdB =

KτB
ετB

+ Kx − 1

Ky

= 1,51 => τmB = τaB =

TB
2 ⋅ WρB

= 7,911 (MPa)

=> sτB =

τ−1

KτdB

⋅ τaB + ψτ

⋅ τmB

= 17,415

=> sB =

sσB ⋅ sτB

√sσB
2 + sτB

2

= 59,996 ≥ [s] = 1,5. . .2,5

- Tại vị trí lắp ổ lăn C:
TC = 83879 (N. mm)

MC = √MxC
2 + MyC

2 = √115482,4
2 + 32166,3

2 = 119879 (N. mm)

dC = 30 mm

WC =

π ⋅ dC

3
32 = 2650,7 (mm³
)

=> σaC =

MC
WC

= 45,225 (MPa); σmC = 0 (MPa)

Chi tiết lắp không có then nên ta lắp chặt, tra bảng 10.11 chọn kiểu lắp k6 ta được:

KσC

εσC

= 2,535

KσdC =

KσC
εσC

+ Kx − 1

Ky

= 1,966 => sσC =

σ−1

KσdC

⋅ σaC + ψσ ⋅ σmC

= 4,169

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

KτC

ετC

= 1,92

35

KτdC =

KτC
ετC

+ Kx − 1

Ky

= 1,51

WρC =

π ⋅ dC

3
16 = 5301,4 (mm³
) => τmC = τaC =

TC
2 ⋅ WρC

= 7,911 (MPa)

=> sτC =

τ−1

KτdC

⋅ τaC + ψτ

⋅ τmC

= 17,415

=> sC =

sσC ⋅ sτC

√sσC
2 + sτC

2

= 15,627 ≥ [s] = 1,5. . .2,5

- Tại vị trí lắp bánh răng dẫn D: dD = 24 (mm)

MD = √MxD
2 + MyD

2 = √0
2 + 8287,5

2 = 8287,5 (N. mm)

WD =

π ⋅ dD

3
32 −

b13 ⋅ t113 ⋅ (dD − t113)

2

2 ⋅ dD

= 1090,5 (mm³
)

=> σaD =

MD
WD

= 7,6 (MPa); σmD = 0 (MPa)

Vị trí có lắp then nên ta tra bảng 10.12 và nội suy nếu cần, ta được

εσD = 0,904 và KσD = 2,073 =>

KσD

εσD

= 2,293

Tra bảng 10.11 chọn kiểu lắp k6 ta được:

KσD

εσD

= 2,293 <

Kσ
εσ

= 2,535 => Chọn

KσD

εσD

= 2,535

KσdD =

KσD
εσD

+ Kx − 1

Ky

= 1,966 => sσD =

σ−1

KσdD

⋅ σaD + ψσ ⋅ σmD

= 24,807

Vị trí có lắp then, nên ta tra bảng 10.12 và nội suy nếu cần, ta được [2]:

ετD = 0,858 và KτD = 1,965 =>

KτD

ετD

= 2,29

Tra bảng 10.11 chọn kiểu lắp k6 ta được:

Kτ
ετ

= 1,92 <

Kτ
ετ

= 2,29 => Chọn

KτD

ετD

= 2,29

36

KτdD =

KτD
ετD

+ Kx − 1

Ky

= 1,784

WρD =

π ⋅ dD

3
16 −

b13 ⋅ t113 ⋅ (dD − t113)

2

2 ⋅ dD

= 2447,7 (mm³
)

=> τmD = τaD =

TD
2 ⋅ WρD

= 17,134 (MPa)

=> sτD =

τ−1

KτdD

⋅ τaD + ψτ

⋅ τmD

= 6,839

=> sD =

sσD ⋅ sτD

√sσD
2 + sτD

2

= 30,157 ≥ [s] = 1,5. . .2,5

Vậy trục 1 thỏa kiểm nghiệm độ bền mỏi tại tất cả các tiết diện

Trục 2:

- Tại A là tiết diện không nguy hiểm do TA = 0 và MA = √MxA
2 + MyA

2 = 0

- Tại vị trí lắp bánh răng bị dẫn B:
dB = 42 (mm)

MB = √MxB
2 + MyB

2 = √146995,7
2 + 0

2 = 146995,7 (N. mm)

WB =

π ⋅ dB

3
32 −

b23 ⋅ t123 ⋅ (dB − t123)

2

2 ⋅ dB

= 6295,7 (mm³
)

=> σaB =

MB
WB

= 23,349 (MPa); σmB = 0 (MPa)

Vị trí có lắp then nên ta tra bảng 10.12 và nội suy nếu cần, ta được

εσB = 0,842 và KσB = 2,073 =>

KσB

εσB

= 2,462

Tra bảng 10.11 chọn kiểu lắp k6 ta được:

KσB

εσB

= 2,462 <

Kσ
εσ

= 2,535 => Chọn

KσB

εσB

= 2,535

KσdB =

KσB
εσB

+ Kx − 1

Ky

= 1,966 => sσB =

σ−1

KσdB

⋅ σaB + ψσ ⋅ σmB

= 8,075

37

Vị trí có lắp then, nên ta tra bảng 10.12 [2] tr.199 và nội suy nếu cần, ta được:

ετB = 0,776 và KτB = 1,965 =>

KτB

ετB

= 2,532

Tra bảng 10.11 chọn kiểu lắp k6 ta được:

KτB

ετB

= 2,532 >

Kτ
ετ

= 1,92 => Chọn

KτB

ετB

= 2,532

KτdB =

KτB
ετB

+ Kx − 1

Ky

= 1,964

WρB =

π ⋅ dB

3
16 −

b23 ⋅ t123 ⋅ (dB − t123)

2

2 ⋅ dB

= 13569,3 (mm³
)

=> τmB = τaB =

TB
2 ⋅ WρB

= 10,428 (MPa)

=> sτB =

τ−1

KτdB

⋅ τaB + ψτ

⋅ τmB

= 10,236

=> sB =

sσB ⋅ sτB

√sσB
2 + sτB

2

= 19,316 ≥ [s] = 1,5. . .2,5

- Tại vị trí lắp ổ lăn C:
TC = 283001(N. mm)

MC = √MxC
2 + MyC

2 = √124426,4
2 + 215512,8

2 = 248852,7 (N. mm)

dC = 40 mm

WC =

π ⋅ dC

3
32 = 6283,2 (mm³
) => σaC =

MC
WC

= 39,606(MPa); σmC = 0 (MPa)

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

KσC

εσC

= 2,535

KσdC =

KσC
εσC

+ Kx − 1

Ky

= 1,966 => sσC =

σ−1

KσdC

⋅ σaC + ψσ ⋅ σmC

= 4,76

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

KτC

ετC

= 1,92

KτdC =

KτC
ετC

+ Kx − 1

Ky

= 1,51

38

WρC =

π ⋅ dC

3
16 = 12566,4 (mm³
) => τmC = τaC =

TC
2 ⋅ WρC

= 11,26(MPa)

=> sτC =

τ−1

KτdC

⋅ τaC + ψτ

⋅ τmC

= 12,235

=> sC =

sσC ⋅ sτC

√sσC
2 + sτC

2

= 14,127 ≥ [s] = 1,5. . .2,5

- Tại vị trí lắp đĩa xích D dD = 36 (mm)

WD =

π ⋅ dD

3
32 −

2 ⋅ t122 ⋅ (dD − t122)

2

2 ⋅ dD

= 3779,6 (mm³
)

=> σaD =

MD
WD

= 0 (MPa); σmD = 0

Do MD = √MxD
2 + MyD

2 = 0 (N. mm) nên chỉ kiểm tra hệ số an toàn ứng suất tiếp

Tra bảng 10.12 và nội suy nếu cần, ta được

ετD = 0,792 và KτD = 1,965 =>

KτD

ετD

= 2,481

Tra bảng 10.11 chọn kiểu lắp k6 ta được:

Kτ
ετ

= 1,92 <

KτD

ετD

= 2,481 => chọn

KτD

ετD

= 2,481

KτdD =

KτD
ετD

+ Kx − 1

Ky

= 1,926

WρD =

π ⋅ dD

3
16 −

b22 ⋅ t122 ⋅ (dD − t122)

2

2 ⋅ dD

= 8360,1 (mm³
)

=> τmD = τaD =

τmaxD
2

=

TD
2 ⋅ WρD

= 16,926 (MPa)

=> sτD =

τ−1

KτdD

⋅ τaD + ψτ

⋅ τmD

= 6,428

=> sD = sτD = 6,428 ≥ [s] = 1,5. . .2,5

Vậy trục 2 thỏa kiểm nghiệm độ bền mỏi tại tất cả các tiết diện

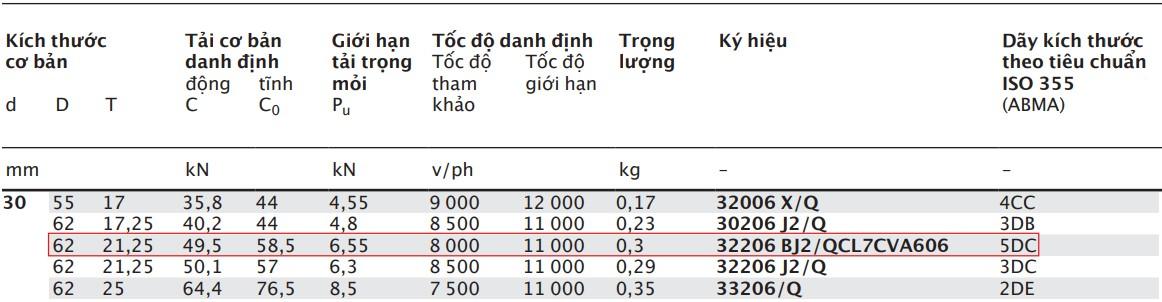
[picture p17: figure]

39

Bảng thông tin kết cấu trục 1:

Vị trí Đường kính trục | Lắp nối trục | Lắp ổ lăn | Lắp ổ lăn | Lắp bánh răng
Trục dẫn | dA = 24 mm | dB = 30 mm | dC = 30 mm | dD = 24 mm

Bảng thông tin kết cấu trục 2:

Vị trí Đường kính trục | Lắp ổ lăn | Bánh răng | Lắp ổ lăn | Lắp đĩa xích
Trục bị dẫn | dA = 40 mm | dB = 42 mm | dC = 40 mm | dD = 36 mm

### 7. Chọn ổ lăn

Trục 1:
Thông số đầu vào:
Đường kính (mm) | dB = 30 | dC = 30
Phản lực tại các gối đỡ trục (N) | RBx = 367,6 | RCx = 1130,7
| RBy = 1915 | RCy = 3764,1
Số vòng quay của trục 1 (vg/ph) | n1 = 715

Tổng lực hướng tâm tại ổ lăn B: FrB = √RBx
2 + RBy

2 = 1950 (N)

Tổng lực hướng tâm tại ổ lăn C: FrC = √RCx
2 + RCy

2 = 3930,3 (N)

=> Chọn ổ đũa côn một dãy lắp theo kiểu lưng đối lưng và tính theo công thức đã cho trong [5], trang 813

40

Bảng thông số ổ đũa côn: , [5] trang 824

Ký hiệu | B (mm) | d | D (mm) | T (mm) | Tải trọng động C (kN) | Tải trọng động C0 (kN) | Hệ số tính toán e | Hệ số tính toán Y
32206 BJ2/QCL7 CVA606 | 20 | 30 | 62 | 21.25 | C = 49,5 | C0 = 58,5 | e = 0,57 | Y = 1,05

Tính toán Tải trọng động của ổ lăn:

Đối với ổ đũa côn một dãy lắp đối xứng

Fa
Fr

≤ e => P = Fr + Y ⋅ Fa hoặc

Fa
Fr

> e => P = 0,67 ⋅ Fr + Y ⋅ Fa

Trong đó: Fa : tải trọng dọc trục của từng ổ được tính toán theo bảng 5 trang 813 [5]; với trị số Ka = Fa1

⋅ 10⁻³ = 0,215 (kN) là tải dọc trục bên ngoài tác động lên trục

FrC
Y

=

3930,3
1,05 = 3743,1 >

FrB
Y

=

1950
1,05 = 1857,1

Ka = 0,215 ≥ 0,5 ⋅

FrB − FrC
Y

= 0,5 ⋅

1950 − 3930,3
1,05 = −942,99

=> Sử dụng trường hợp tải 2b để tính toán

=> FaB =

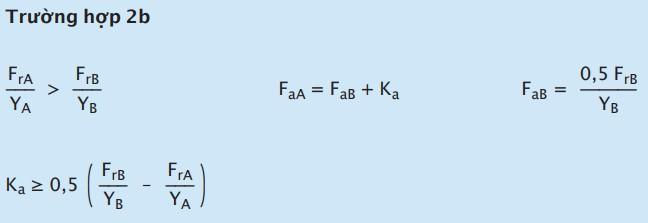
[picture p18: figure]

0,5 ⋅ FrB
Y

= 928,6 (N)

=> aC = FaB + Ka = 928,8 (N)

Tải trọng động của ổ lăn tại C:

FaC

FrC

=

928,8
3930,3

= 0,236 ≤ e = 0,57

=> PC = FrC + Y ⋅ FaC = 3930,3 + 1,05 ⋅ 928,8 = 4905,5 N = 4,9055 kN

Tải trọng động của ổ lăn tại B:

FaB

FrB

=

928,6
1950 = 0,476 ≤ e = 0,57

41

=> PB = FrB + Y ⋅ FaB = 1950 + 1,05 ⋅ 928,6 = 2925 N = 2,925 Kn

- Tuổi thọ danh định cơ bản theo tiêu chuẩn ISO 281 được tính theo công thức

L10 = (

C
P

)

p
(t iệu vòng qua )

=> L10C = (

C
PC

)

10
3
= (

49,5
4,9055)

10
3
= 2220,3 (t iệu vòng qua )

=> L10B = (

C
PB

)

10
3
= (

49,5
2,925)

10
3
= 12443,5 (t iệu vòng qua )
- Nếu tốc độ không thay đổi, thông thường tuổi thọ sẽ được tính theo số giờ hoạt động, sử dụng công thức:

L10ℎC =

L10C ⋅ 10⁶
60 ⋅ n1

=

2220,3 ⋅ 10⁶
60 ⋅ 715 = 51755,6 (giờ) ≥ LH = 18000 (giờ)

L10ℎB =

L10B ⋅ 10⁶
60 ⋅ n1

=

12443,5 ⋅ 10⁶
60 ⋅ 715 = 290059 (giờ) ≥ LH = 18000 (giờ)

Trong đó:
L10 : Tuổi thọ danh định cơ bản (với độ tin cậy 90%)

L10ℎ : Tuổi thọ danh định cơ bản (với độ tin cậy 90%)

LH : Thời gian làm việc

C: tải trọng động danh định cơ bản (kN)

P: tải trọng động tương đương tác dụng lên ổ lăn (kN)

n1

: tốc độ quay trục 1 (vg/ph)

p: số mũ của công thức tính tuổi thọ (ổ đũa p =
| 10
| 3

)

Trục 2:
Thông số đầu vào:
Đường kính (mm) | dA = 40 | dC = 40
Phản lực tại các gối đỡ trục (N) | RAx = 356,5 | RCx = 3602,9
| RAy = 2027,5 | RCy = 1599,1
Số vòng quay của trục 1 (vg/ph) | n1 = 201,4
Tổng lực hướng tâm tại ổ lăn B FrA = √RAx
2 + RAy

2 = 2058,6 (N)

42

Tổng lực hướng tâm tại ổ lăn C FrC = √RCx
2 + RCy

2 = 3941,8 (N)

=> Chọn ổ đũa côn một dãy lắp theo kiểu lưng đối lưng và tính theo công thức đã cho trong [5], trang 813
Chọn loại ổ lăn: chọn từ cataloge SKF trang 824

Bảng thông số ổ đũa côn: [5] trang 824

Ký hiệu | B (mm) | d | D (mm) | T (mm) | Tải trọng động C (kN) | Tải trọng động C0 (kN) | Hệ số tính toán e | Hệ số tính toán Y
33108 /Q | 23 | 40 | 75 | 26 | C = 79,2 | C0 = 104 | e = 0,35 | Y = 1,7
- Tính toán Tải trọng động của ổ lăn:

Đối với ổ đũa côn một dãy lắp đối xứng

Fa
Fr

≤ e => P = Fr + Y ⋅ Fa ℎoặc

Fa
Fr

> e => P = 0,67 ⋅ Fr + Y ⋅ Fa

Trong đó: Fa : tải trọng dọc trục của từng ổ lăn được tính toán theo bảng 5 trang 813 [5]; với trị số Ka = Fa2

⋅ 10⁻³ = 0,7631 (kN) là tải dọc trục bên ngoài tác động lên trục

FrC
Y

=

3941,8
1,7

= 2318,7 >

FrA
Y

=

2058,6
1,7

= 1211

Ka = 0,7631 ≥ 0,5 ⋅

FrA − FrC
Y

=

2058,6 − 3941,8
2 ⋅ 1,7

= −553,9

=> Sử dụng trường hợp tải 2b để tính toán

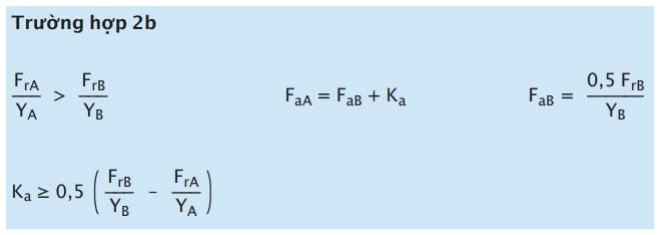
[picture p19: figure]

43

=> FaA =

0,5 ⋅ FrA
Y

=

0,5 ⋅ 2058,6
1,7

= 605,5 (N)

=> aC = FaA + Ka = 605,5 + 0,7631 = 606,3 (N)

Tải trọng động của ổ lăn tại C:

FaC

FrC

=

606,3
3941,8

= 0,154 ≤ e = 0,35

=> PC = FrC + Y ⋅ FaC = 3941,8 + 1,7 ⋅ 606,3 = 4972,4 (N) = 4,9724 (kN)

Tải trọng động của ổ lăn tại A:

FaA

FrA

=

605,5
2058,6

= 0,294 ≤ e = 0,35

=> PA = FrA + Y ⋅ FaA = 2058,6 + 1,7 ⋅ 605,5 = 3088 (N) = 3,088 (kN)

- Tuổi thọ danh định cơ bản theo tiêu chuẩn ISO 281 được tính theo công thức

L10 = (

C
P

)

p
(t iệu vòng qua )

=> L10C = (

C
PC

)

10
3
= (

79,2
4,9724)

10
3
= 10166,8 (t iệu vòng qua )

=> L10A = (

C
PA

)

10
3
= (

79,2
3,088)

10
3
= 49756 (t iệu vòng qua )
- Nếu tốc độ không thay đổi, thông thường tuổi thọ sẽ được tính theo số giờ hoạt động, sử dụng công thức:

L10ℎC =

L10C ⋅ 10⁶
60 ⋅ n2

=

10166,8 ⋅ 10⁶
60 ⋅ 201,4

= 841310,8 (giờ) ≥ LH = 18000 (giờ)

L10ℎA =

L10A ⋅ 10⁶
60 ⋅ n2

=

49756 ⋅ 10⁶
60 ⋅ 201,4

= 411734,1 (giờ) ≥ LH = 18000 (giờ)

Trong đó:
L10 : Tuổi thọ danh định cơ bản (với độ tin cậy 90%)

L10ℎ : Tuổi thọ danh định cơ bản (với độ tin cậy 90%)

LH : Thời gian làm việc

C: tải trọng động danh định cơ bản (kN)

P: tải trọng động tương đương tác dụng lên ổ lăn (kN

n1

: tốc độ quay trục 1 (vg/ph)

p: số mũ của công thức tính tuổi thọ (ổ đũa p =

10
3

)

44

### 8. Tính toán vỏ hộp, các chí tiết phụ

Chỉ tiêu của vỏ hộp giảm tốc là độ cứng cao và khối lượng nhỏ. Chọn vật liệu để đúc hộp giảm tốc là gang xám có kí hiệu GX 15-32.

Chọn bề mặt ghép nắp và thân đi qua tâm trục.

Các kích thước của các phần tử cấu tạo nên hộp giảm tốc đúc: [6], trang 85

Tên gọi | Biểu thức tính toán
Chiều dày: Thân hộp, δ Nắp hộp, δ1 | δ = 0,03 a + 3 = 0,03 162+ 3 = 7,9 mm > 6mm Chọn δ = 8 mm δ1 = δ = 8 mm
Gân tăng cứng: Chiều dày, e Chiều cao, h Độ dốc | e = (0,8 ÷ 1) δ , chọn e = 8 mm h < 58, Khoảng 2o
Đường kính: Bulông nền, d1 Bulông cạnh ổ, d2 Bulông ghép bích nắp và thân, d3 Vít ghép nắp ổ, d4 Vít ghép nắp cửa thăm dầu, d5 | d1 = 0,04 a+10 = 0,04 162 + 10 =16,5 Chọn d1 =16 mm d2 = (0,7 ÷ 0,8) d1 , chọn d2 = 12 mm d3 = (0,8 ÷ 0,9) d2 , chọn d3 = 10mm d4 = (0,6 ÷ 0,7) d2 , chọn d4 = 8 mm d5 = (0,5 ÷ 0,6) d2 , chọn d5 = 8 mm
Mặt bích ghép nắp và thân: Chiều dày bích thân hộp, S3 Chiều dày bích nắp hộp, S4 Bề rộng bích nắp hộp, K3 | S3 = (1,4 ÷ 1,8) d3 , chọn S3 = 16 mm S4 = (0,9 ÷ 1) S3, chọn S4 = 16 mm K3 = K2 – (3 ÷ 5) mm = 39 – 4 = 35 mm
Kích thước gối trục: Đường kính ngoài và tâm lỗ vít, D3, D2 | Định theo kích thước nắp ổ

45

Bề rộng mặt ghép bulông cạnh ổ: K2 Tâm lỗ bulông cạnh ổ: E2 và C (k là khoảng cách từ tâm bulông đến mép lỗ) Chiều cao h | K2 = E2 + R2 + (3÷5) mm = 19 + 16 + 4 = 39 mm E2= 1,6 d2 = 1,6 12 = 19,2 mm, chọn E2 = 19 mm R2 = 1,3 d2 = 1,3 12 = 15,6 mm, chọn R2 = 16 mm C = D3/2; k ≥ 1,2 ⋅ d_2 = 14,4 h: phụ thuộc tâm lỗ bulông và kích thước mặt tựa
Mặt đế hộp: Chiều dày: Khi không có phần lồi S1 Khi có phần lồi S1 Bề rộng mặt đế hộp, K1 và q | S1 = (1,3÷1,5) ⋅ d1 , chọn S1 = 24 mm S1 = (1,4÷1,7) ⋅ d1 , chọn S1 = 24 mm K1 = 3 ⋅ d1 = 3 ⋅ 16 = 48 mm q = K1 + 2 ⋅ δ = 48 + 2 ⋅ 8 = 64 mm
Khe hở giữa các chi tiết: Giữa bánh răng với thành trong hộp Giữa đỉnh bánh răng lớn với đáy hộp Giữa mặt bên các bánh răng với nhau. | Δ ≥ (1 ÷ 1,2) δ, chọn Δ = 10 mm Δ1 ≥ (3 ÷ 5) δ, chọn Δ1 = 25 mm Δ2 ≥ δ , chọn Δ2 = 10 mm
Số lượng bulông nền Z | Z = ( L + B ) / ( 200 ÷300) = 700 / 200 = 3,5 chọn Z = 4
- Kích thước gối trục

Tra bảng 18.2 [6] tr.88 ta có các kích thước gối trục:

Trục | D, mm | D2, mm | D3, mm | d4, mm | z
1 | 75 | 90 | 115 | M8 | 6
2 | 75 | 90 | 115 | M8 | 6

8.1 Chi tiết phụ

- Bulong vòng
Chức năng để nâng và vận chuyển hộp giảm tốc (khi gia công, khi lắp ghép, …) trên nắp và thân thường lắp them bu lông vòng

Vật liệu: Thép 20

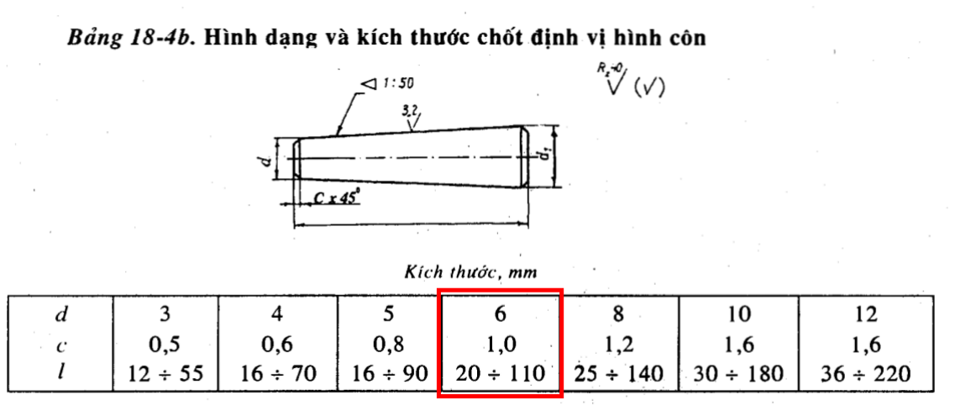
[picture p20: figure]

46

Số lượng: 2 chiếc

Chọn Bulong vòng M8

Thông số bu lông vòng tra bảng 18.3a [6] tr.89 ta được:

Ren d | d1 | d2 | d3 | d4 | d5 | h | ℎ1 | ℎ2 | l ≥ | f | b | c | x | r1 | r2
M8 | 36 | 20 | 8 | 20 | 13 | 18 | 6 | 5 | 18 | 2 | 10 | 1,2 | 2,5 | 4 | 4
- Chốt định vị
Để đảm bảo vị trí tương đối của nắp và thân trước, thân sau, khi gia công cũng như khi lắp ghép ta chế tạo thêm chốt định vị. Theo bảng 18.4b [6] tr.91 ta có các kích thước chốt định vị chốt côn như sau:

d = 6 mm; c = 1 mm; l = 42 mm

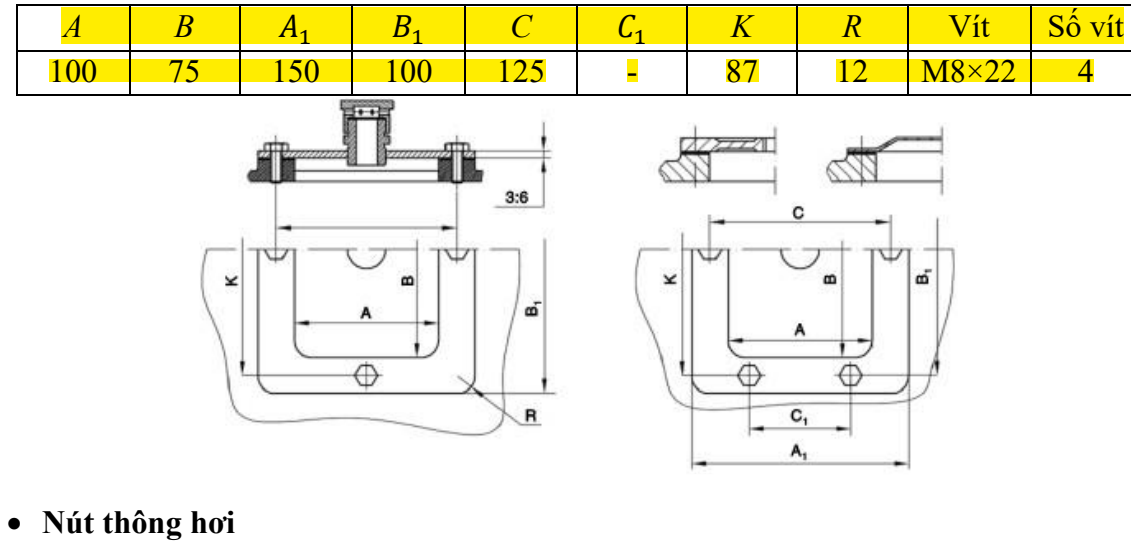
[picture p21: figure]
Vít; Số vít; • Nút thông hơi
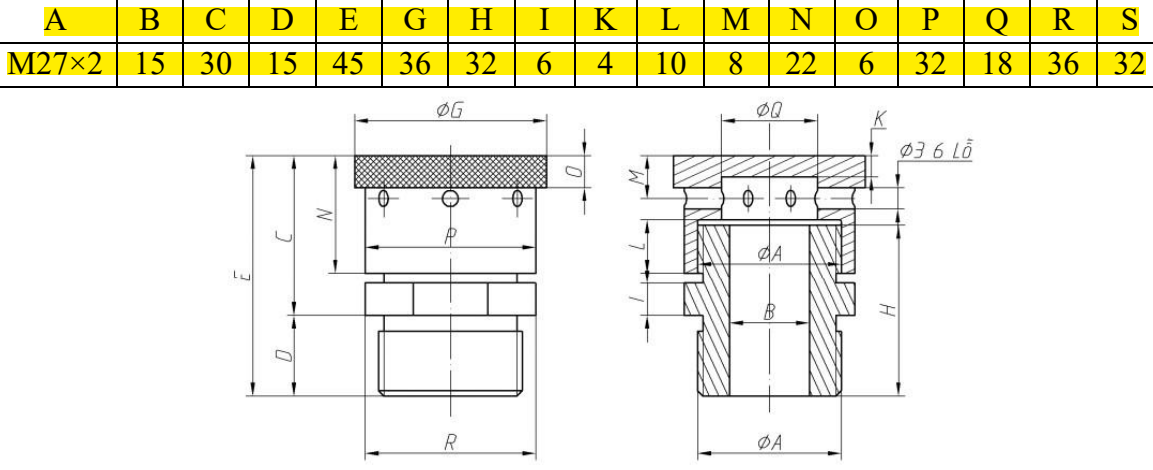
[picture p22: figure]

47

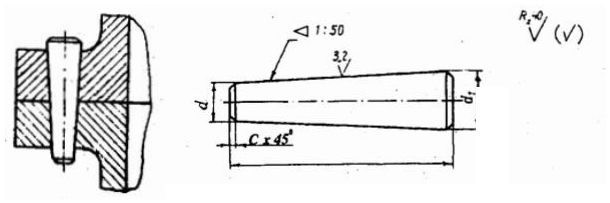
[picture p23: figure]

- Cửa thăm

Để đổ dầu vào hộp và quan sát các chi tiết trong hộp khi lắp ghép cần có cửa thăm. Theo bảng 18.5 [6] tr.92 ta chọn cửa thăm có các kích thước như sau:

Khi làm việc nhiệt độ trong hộp tăng lên, để giảm áp suất và điều hòa không khí trong và ngoài hộp nên ta dùng nút thông hơi. Kích thước nút thông hơi chọn theo bảng 18.6
[6] tr.93

48

- Nút tháo dầu

Nút tháo dầu để tháo dầu bẩn, biến chất để thay dầu mới. Theo bảng 18.7 [6] tr.93 có kích thước nút tháo dầu như sau:

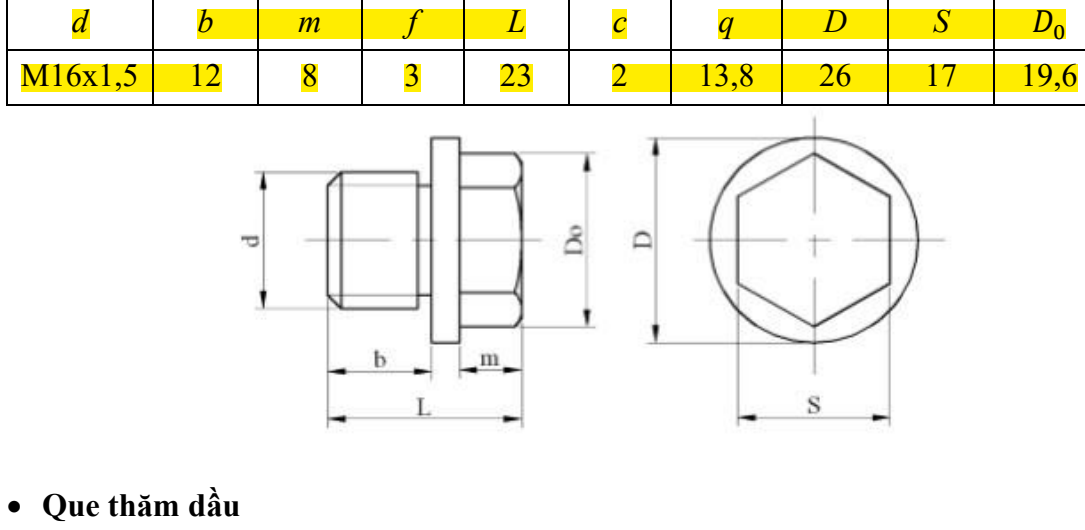
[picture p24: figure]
• Que thăm dầu

Để kiểm tra mức dầu trong hộp ta dùng que thăm dầu.

49

## Tài liệu tham khảo

[1] H. L. Viên, “Các máy gia công vật liệu rắn & dẻo - Tập 2,” NXB KHKТ, 2003.
[2] Trịnh Chất, Lê Văn Uyển, “Tinh toán thiết kế hệ dẫn động cơ khí - tập 1,” NXB Giáo

dục , 2006.

[3] C. BB, “Low voltage General performance cast iron motors for sian,” 2023.
[4] T. T. Phúc, "Thiết kế chi tiết máy công dụng chung," NXB ĐHQG, 2011.
[5] SKF, catalogue.
[6] Trịnh Chất, Lê Văn Uyển , “Tinh toán thiết kế hệ dẫn động cơ khí - tập 2,” NXB

Giáo dục , 2006.

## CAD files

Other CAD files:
2.dwg

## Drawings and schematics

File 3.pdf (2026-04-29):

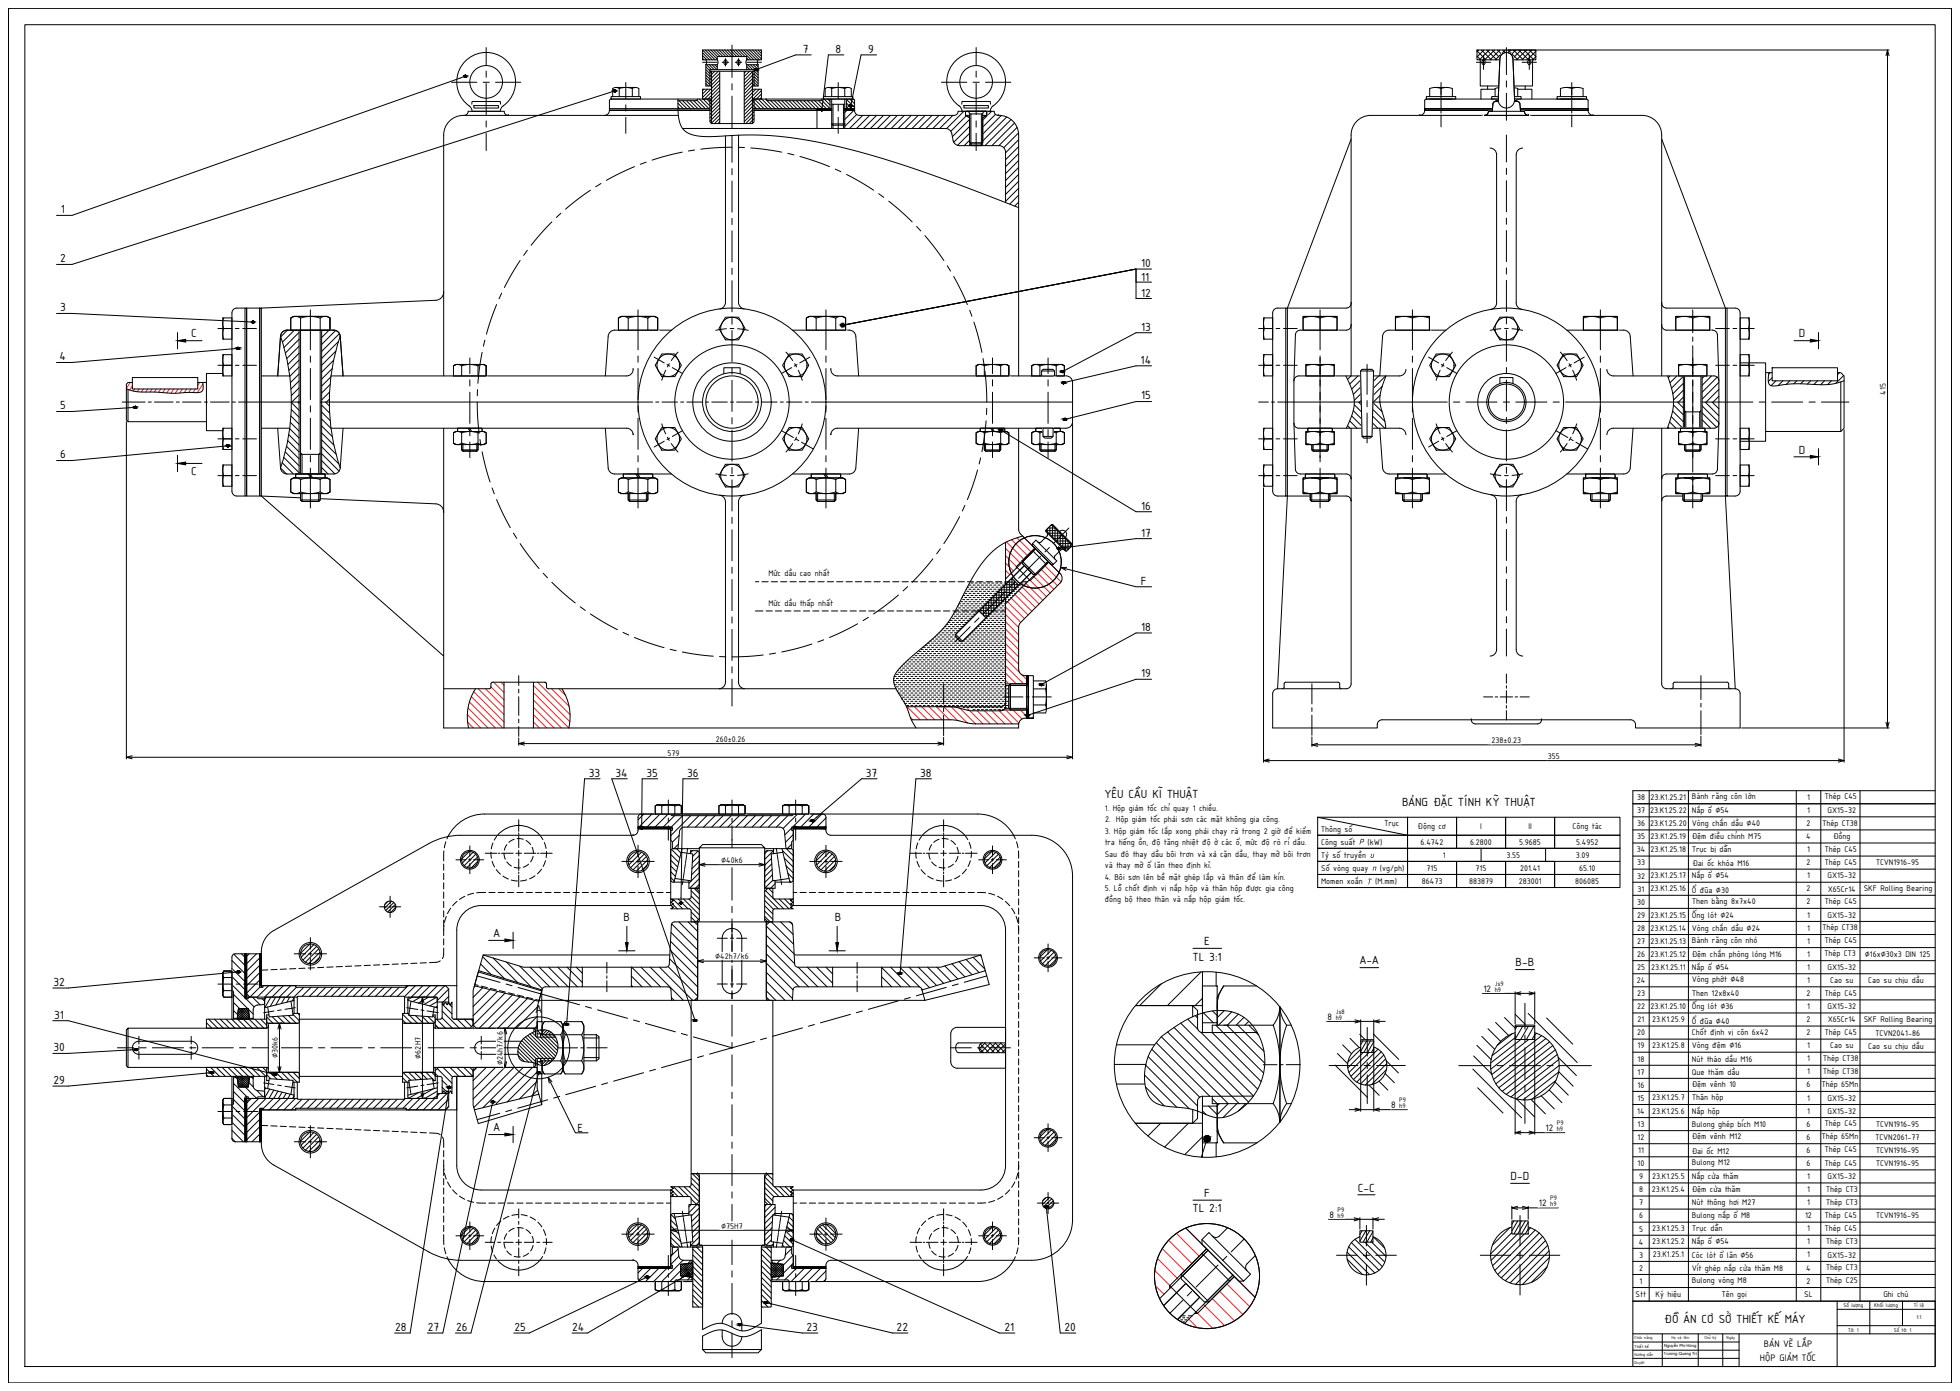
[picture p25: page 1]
YÊU CẦU KĨ THUẬT 1. Hộp giảm tốc chỉ quay 1 chiều. 2. Hộp giảm tốc phải sơn các mặt không gia công. 3. Hộp giảm tốc lắp xong phải chạy rà trong 2 giờ để kiểm tra tiếng ồn, độ tăng nhiệt độ ở các ổ, mức độ rò rỉ dầu. Sau đó thay dầu bôi trơn và xả cặn dầu, thay mỡ bôi trơn và thay mỡ ổ lăn theo định kì. 4. Bôi sơn lên bề mặt ghép lắp và thân để làm kín. 5. Lỗ chốt định vị nắp hộp và thân hộp được gia công đồng bộ theo thân và nắp hộp giảm tốc.; Động cơ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

∅62H7 E E TL 3:1 123456789101112131415161718192021 22232425262728293031 3234353633 Stt Ký hiệu Tên gọi SL Ghi chú Bulong vòng M8 Vít ghép nắp cửa thăm M8 Cóc lót ổ lăn ∅56 Nắp ổ ∅54 Trục dẫn Bulong nắp ổ M8 Nút thông hơi M27 Đệm cửa thăm Nắp cửa thăm Bulong M12 Bulong ghép bích M10 Nắp hộp Thân hộp Đệm vênh 10 Que thăm dầu Nút tháo dầu M16 Ổ đũa ∅40 Vòng phớt ∅48 Đệm chắn phòng lỏng M16 Bánh răng côn nhỏ Vòng chắn dầu ∅24 Ống lót ∅24 Then bằng 8x7x40 Ổ đũa ∅30 Đai ốc khóa M16 Trục bị dẫn Vòng chắn dầu ∅40 Bánh răng côn lớn Chốt định vị côn 6x42 241111211166116112211111122212112 X65Cr14 23.K1.25.1 23.K1.25.2 23.K1.25.3 23.K1.25.4 Đai ốc M12 Đệm vênh M12 Then 12x8x40 Nắp ổ ∅54 23.K1.25.14 Nắp ổ ∅54 23.K1.25.20 23.K1.25.19 23.K1.25.18 23.K1.25.21 23.K1.25.13 23.K1.25.12 23.K1.25.11 23.K1.25.9 23.K1.25.6 23.K1.25.5 23.K1.25.15 23.K1.25.17 Đệm điều chỉnh M75 4 23.K1.25.8 Vòng đệm ∅16 1 Cao su chịu dầu Đồng GX15-32 Nắp ổ ∅54 1 23.K1.25.16 GX15-32 37 SKF Rolling Bearing Thép C25 Thép CT3 GX15-32 Thép CT3 Thép CT3 GX15-32 Thép 65Mn GX15-32 Thép CT38 Cao su X65Cr14 Cao su Thép CT38 Thép CT38 Thép 65Mn GX15-32 GX15-32 Thép C45 Thép CT3 ∅16x∅30x3 DIN 125 GX15-32 Cao su chịu dầu SKF Rolling Bearing 66 23.K1.25.7 Thép C45 Thép C45 Thép C45 Thép C45 Thép C45 Thép C45 Thép C45 Thép C45 Thép C45 Thép C45 Thép C45 TCVN2041-86 TCVN1916-95 TCVN2061-77 TCVN1916-95 TCVN1916-95 TCVN1916-95 38 23.K1.25.10 Ống lót ∅36 1 GX15-32 23.K1.25.22 Thép CT3 Thép CT38 TCVN1916-95 ∅75H7 260±0.26 579 238±0.23 355 1112 654321 7 8 9 16151413191817 28 27 26 25 24 23 22 21 20 293031 32 33 34 35 36 37 38 10F

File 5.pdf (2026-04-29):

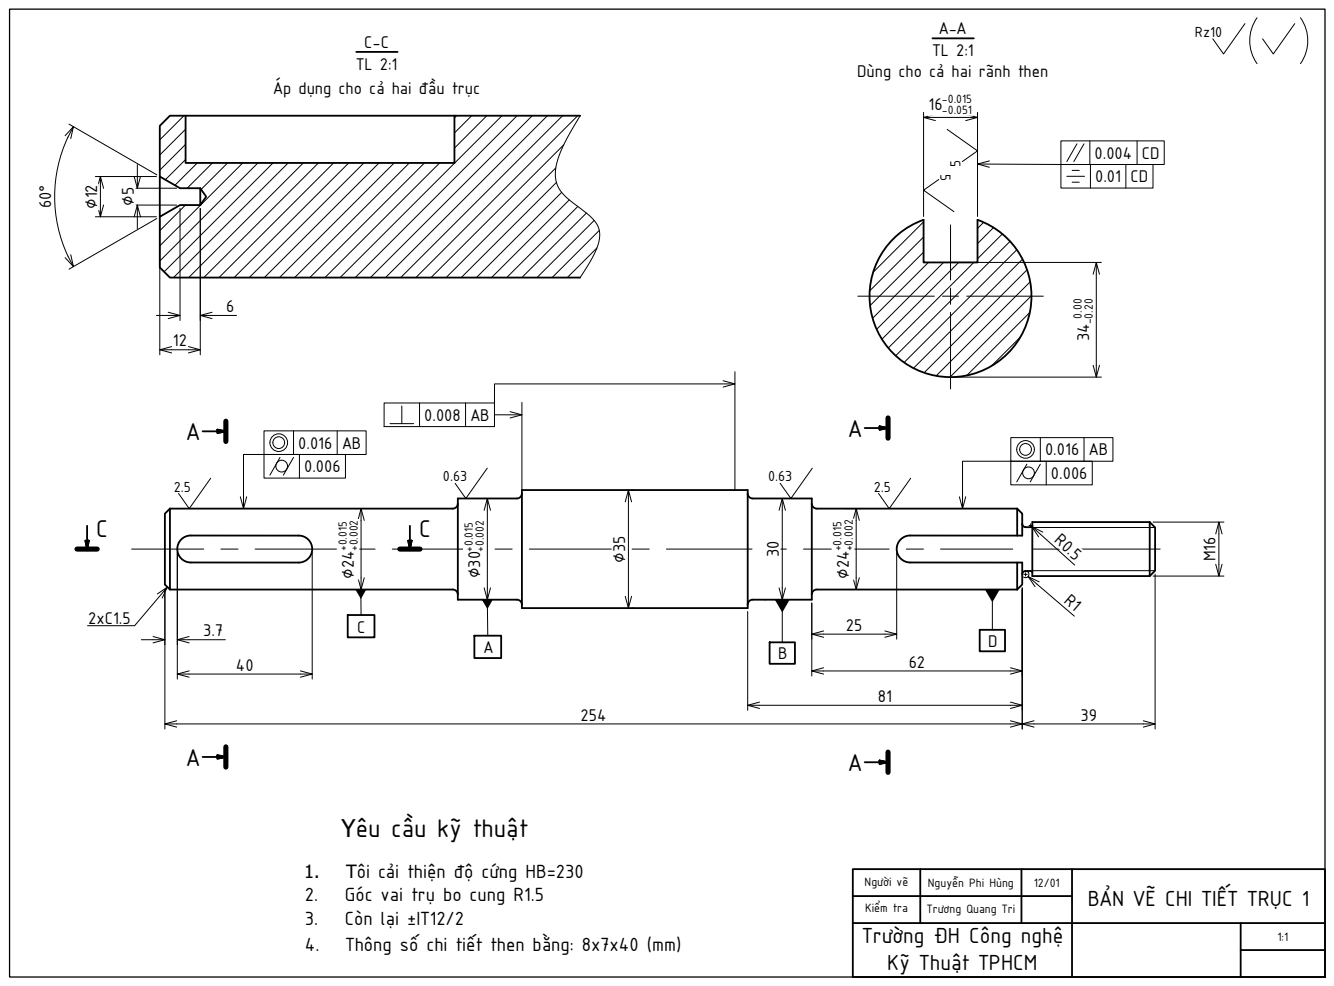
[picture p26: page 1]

∅5 C-C TL 2:1 Áp dụng cho cả hai đầu trục A-A TL 2:1 Dùng cho cả hai rãnh then

+0.002 A B A 2.5 AA C A Rz10 Yêu cầu kỹ thuật 1. Tôi cải thiện độ cứng HB=230 2. Góc vai trụ bo cung R1.5 3. Còn lại ±IT12/2 4. Thông số chi tiết then bằng: 8x7x40 (mm)

+0.002 Người vẽ Kiểm tra Nguyễn Phi Hùng Trương Quang Tri 12/01 Trường ĐH Công nghệ Kỹ Thuật TPHCM BẢN VẼ CHI TIẾT TRỤC 1 1:1 254 R0.5 3.7 40 R1 39
